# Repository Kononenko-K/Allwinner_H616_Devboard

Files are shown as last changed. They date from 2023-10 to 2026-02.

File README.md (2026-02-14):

# Allwinner_H616_Devboard
A minimalistic development board designed for the Cortex-A53 Allwinner H616 SoC using KiCad

<p align="center">
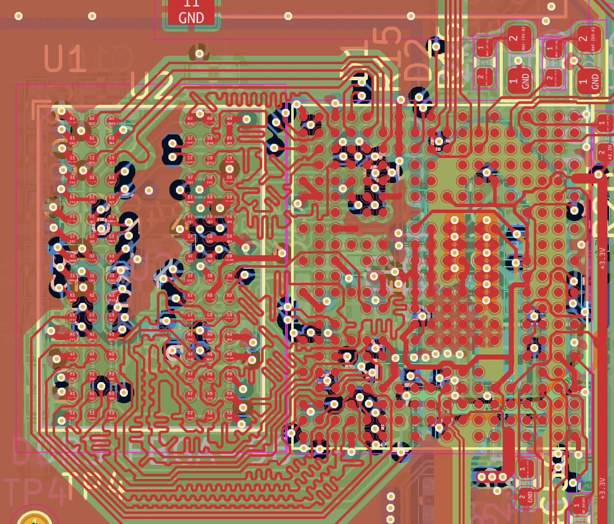
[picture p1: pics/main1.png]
     
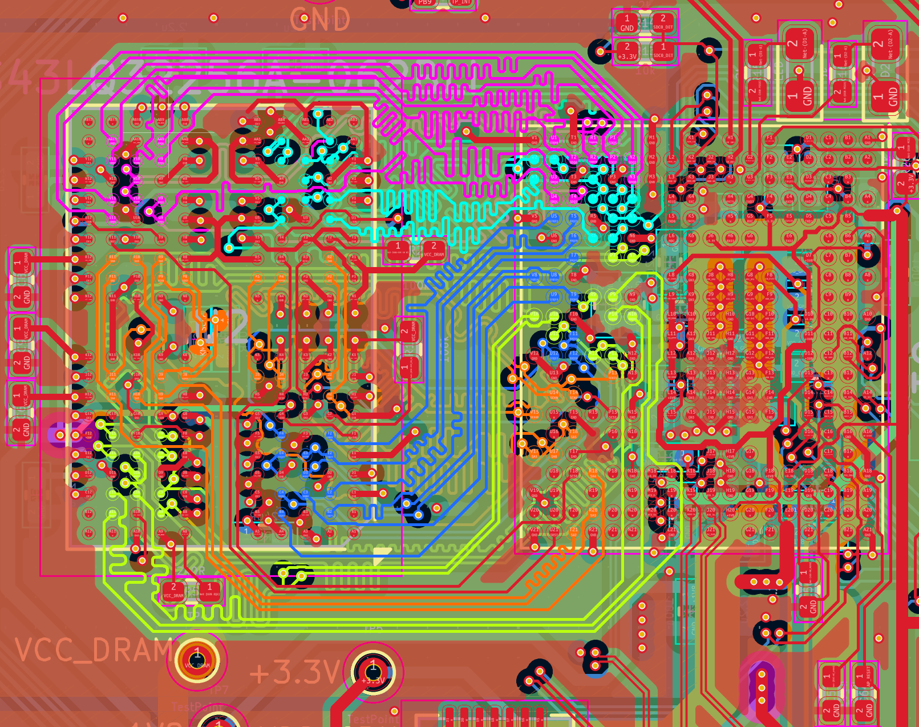
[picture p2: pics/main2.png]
     
</p>

## Overview
The goal of this project, based on the schematics of Orange Pi Zero 2 and Orange Pi Zero 3, was to create a minimalistic development board for the H616 SoC with a functional DDR3/LPDDR4 topology and power supply. This allows it to be used as a basic design that can be modified for specific applications.

## [Hardware](Hardware)
Both versions of the board are powered by the 64-bit 1.5GHz Quad-Core Cortex-A53 Allwinner H616 SoC, supporting either Allwinner H616 or its pin-to-pin compatible successor, Allwinner H618. The primary difference between these chips is the increased L2 cache size in the H618 model.
#### [DDR3 Version:](/Hardware/H616_DDR3)
<p align="center">
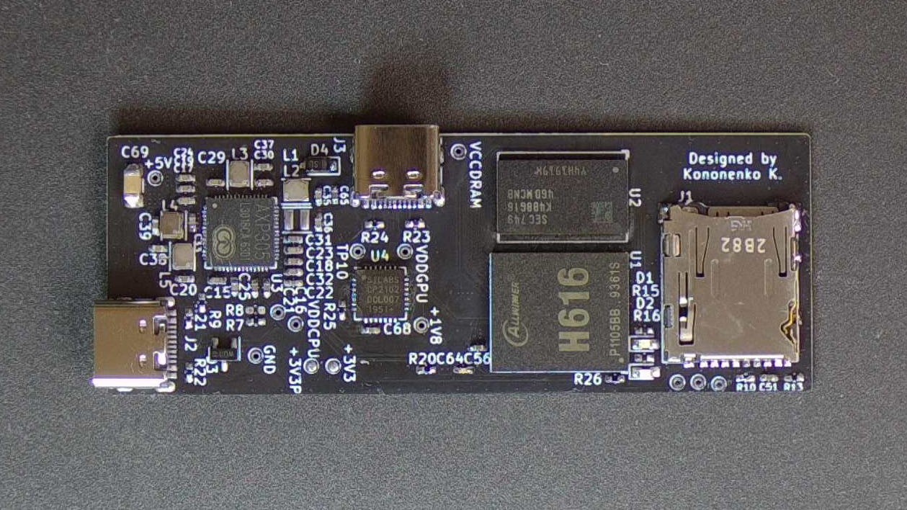
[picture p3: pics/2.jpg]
     
</p>

The DDR3 variant features a compact design optimized for simplicity and ease of learning. Key components include:

- **Memory:** Up to 8 Gbit (1 GB) of BGA-96 16x DDR3 RAM
- **Power Management:** X-Powers AXP305 PMIC
- **Connectivity:** Micro SD slot, USB HS Host connector
- **Communication:** Integrated CP2102 USB-UART converter

#### [LPDDR4 Version:](/Hardware/H616_LPDDR4)
<p align="center">
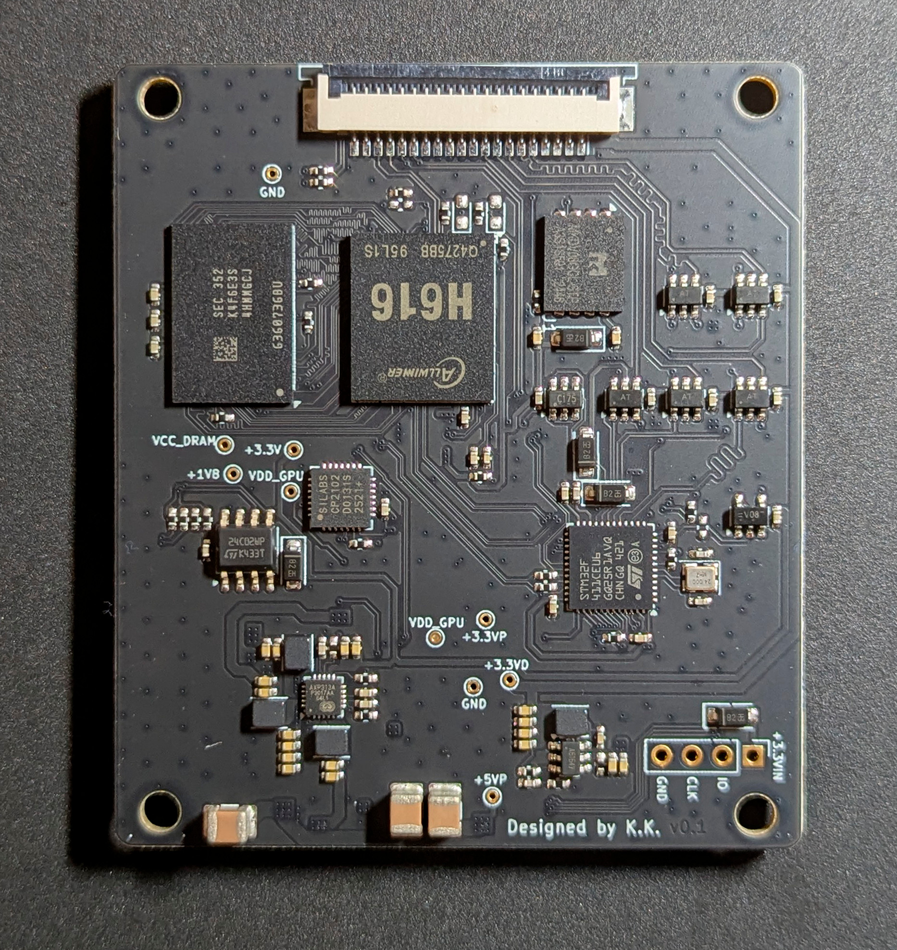
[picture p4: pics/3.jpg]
     
</p>

The LPDDR4 variant offers enhanced capabilities tailored for my specific application, while also remaining suitable for educational use:

- **Memory:** Up to 32 Gbit (4 GB) of BGA-200 32x LPDDR4 RAM
- **Power Management:** X-Powers AXP313A PMIC
- **Storage:** Integrated SD2.0 Flash Memory chip and MicroSD slot for flexible storage options
- **Auxiliary Processing:** Cortex-M4 STM32 microcontroller for additional processing tasks
- **Communication:** Integrated CP2102 USB-UART converter

To power the board via USB and connect external devices, a custom [USB board adapter](/Hardware/Debug_Adapter) is available.

### **Manufacturing specifications:**
- **Layers:** 4-layer design  
- **Trace/Space:** 3.5/3.5 mil  
- **Via Sizes:** 0.35/0.15 mm 
- **Prepreg:** 80u  

There are PDF documents available for both [DDR3](/Hardware/H616_DDR3/project.pdf) and [LPDDR4](/Hardware/H616_LPDDR4/project.pdf) versions.

## Software

### **Building from Mainline:**
#### Arm Trusted Firmware (TF-A):
- Source: [here](https://git.trustedfirmware.org/TF-A/trusted-firmware-a.git/)
```sh
make CROSS_COMPILE=aarch64-linux-gnu- PLAT=sun50i_h616 RESET_TO_BL31=1
```
After building, copy the `bl31.bin` file to the U-Boot sources directory.

#### U-Boot:
- Source: [here](https://github.com/u-boot/u-boot)
```sh
make ARCH=arm CROSS_COMPILE=aarch64-linux-gnu- orangepi_zero2_defconfig
make ARCH=arm CROSS_COMPILE=aarch64-linux-gnu- BL31=bl31.bin
```

#### Linux Kernel:
- Source: [www.kernel.org](http://www.kernel.org)
```sh
make ARCH=arm64 CROSS_COMPILE=aarch64-linux-gnu- defconfig
make ARCH=arm64 CROSS_COMPILE=aarch64-linux-gnu- Image modules dtbs
```

#### Rootfs:
Example sources for arm64 rootfs:
- [rcn-ee.com](https://rcn-ee.com/rootfs/eewiki/minfs)
- [Linaro.org](https://releases.linaro.org/openembedded/images/)

#### Preparing SD Card:
1. Create two partitions: a small fat32 for boot files and an ext4 for rootfs.
2. Write U-Boot to the card:
```sh
sudo dd if=/dev/zero of=/dev/mmcblk0 bs=1k count=1023 seek=1
sudo dd if=u-boot-sunxi-with-spl.bin of=/dev/mmcblk0 bs=1024 seek=8
```
3. Copy dtb and kernel image to the first partition, then unpack rootfs to the second.

If you prefer to load U-Boot into RAM and execute it directly over USB without using an SD card, you can use the `sunxi-fel` utility:  
   ```sh
   sudo sunxi-fel uboot u-boot-sunxi-with-spl.bin
   ```  
This method is useful for testing or when bypassing the SD card for some reason.

#### Booting from U-Boot:
Enter these commands in the U-Boot console:
```sh
setenv bootargs console=ttyS0,115200 root=/dev/mmcblk0p2 rw rootwait
setenv bootcmd "mmc rescan; fatload mmc 0:1 0x46000000 Image; fatload mmc 0:1 0x49000000 sun50i-h616-orangepi-zero2.dtb; booti 0x46000000 - 0x49000000"
```
Use a `boot.scr` file for automatic booting.

### **Using Buildroot:**
For LPDDR4 version:
```sh
make orangepi_zero3_defconfig
```
For DDR3 versions, modify the config:
```sh
BR2_LINUX_KERNEL_INTREE_DTS_NAME="allwinner/sun50i-h616-orangepi-zero2.dts"
BR2_TARGET_UBOOT_BOARD_DEFCONFIG="orangepi_zero2"
```
Download sources with `make source`, then build.

## License
- The **Hardware** in this project is licensed under the [CERN Open Hardware Licence Permissive (CERN OHL-P)](LICENSE).

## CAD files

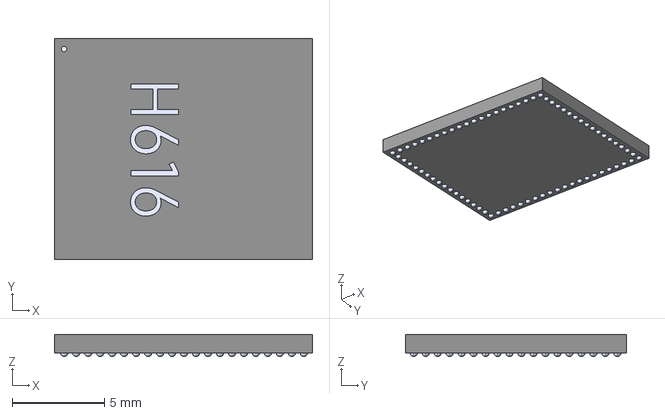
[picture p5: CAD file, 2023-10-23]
Hardware/H616_DDR3/SoC_H616.step
14.0 x 12.0 x 1.20 mm

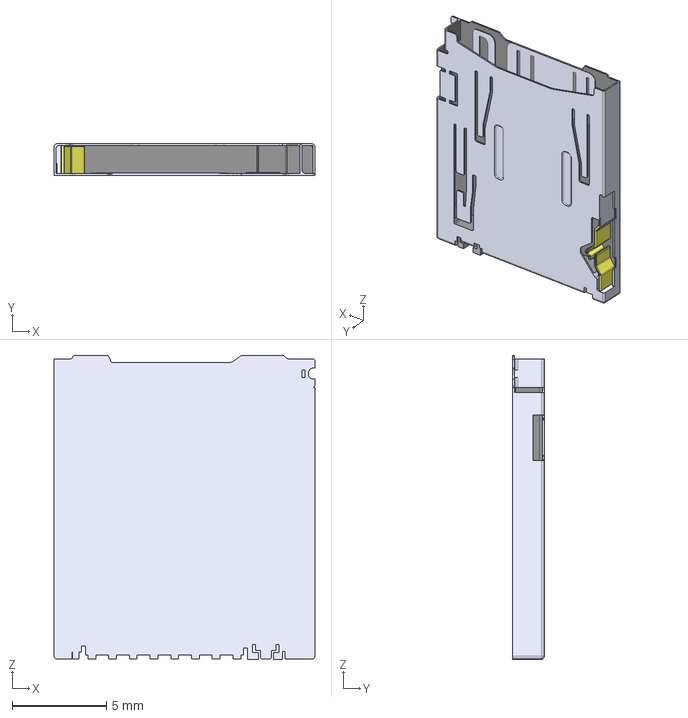
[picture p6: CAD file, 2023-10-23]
Hardware/H616_LPDDR4/MicroSD_DM3AT.step
13.8 x 1.68 x 16.2 mm

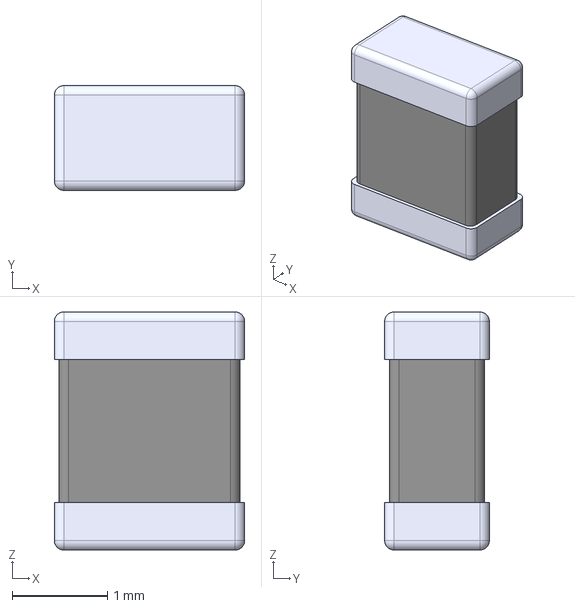
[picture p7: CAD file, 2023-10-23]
Hardware/H616_LPDDR4/Inductor_2520.step
2.00 x 1.10 x 2.50 mm

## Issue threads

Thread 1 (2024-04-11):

BOM

TechyGuy17, 2024-04-11:
Hello!

I love this project, been looking for a good and simple h616 circuit and this is great!!

Do you have any recommendation regarding sourcing? For example the AXP305 seems to have dissapered from lcsc, do you solder it yourself?

And is there a reason you use a 25mhz reference clock instead of the recommended 24 in the datasheet of the h616?

Thanks!

Closed 2024-04-18.

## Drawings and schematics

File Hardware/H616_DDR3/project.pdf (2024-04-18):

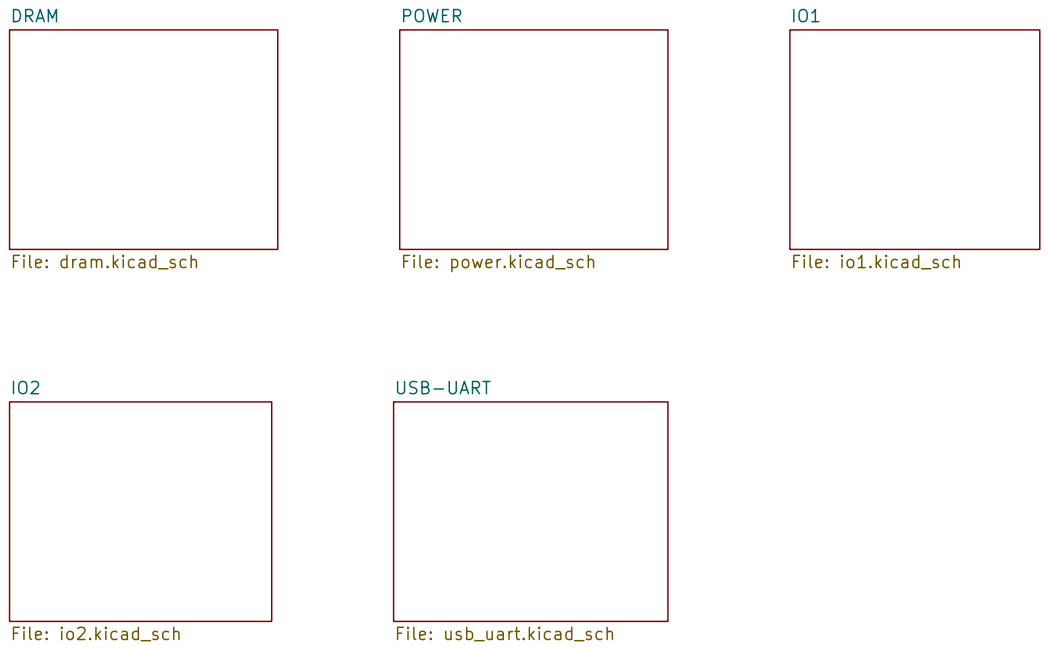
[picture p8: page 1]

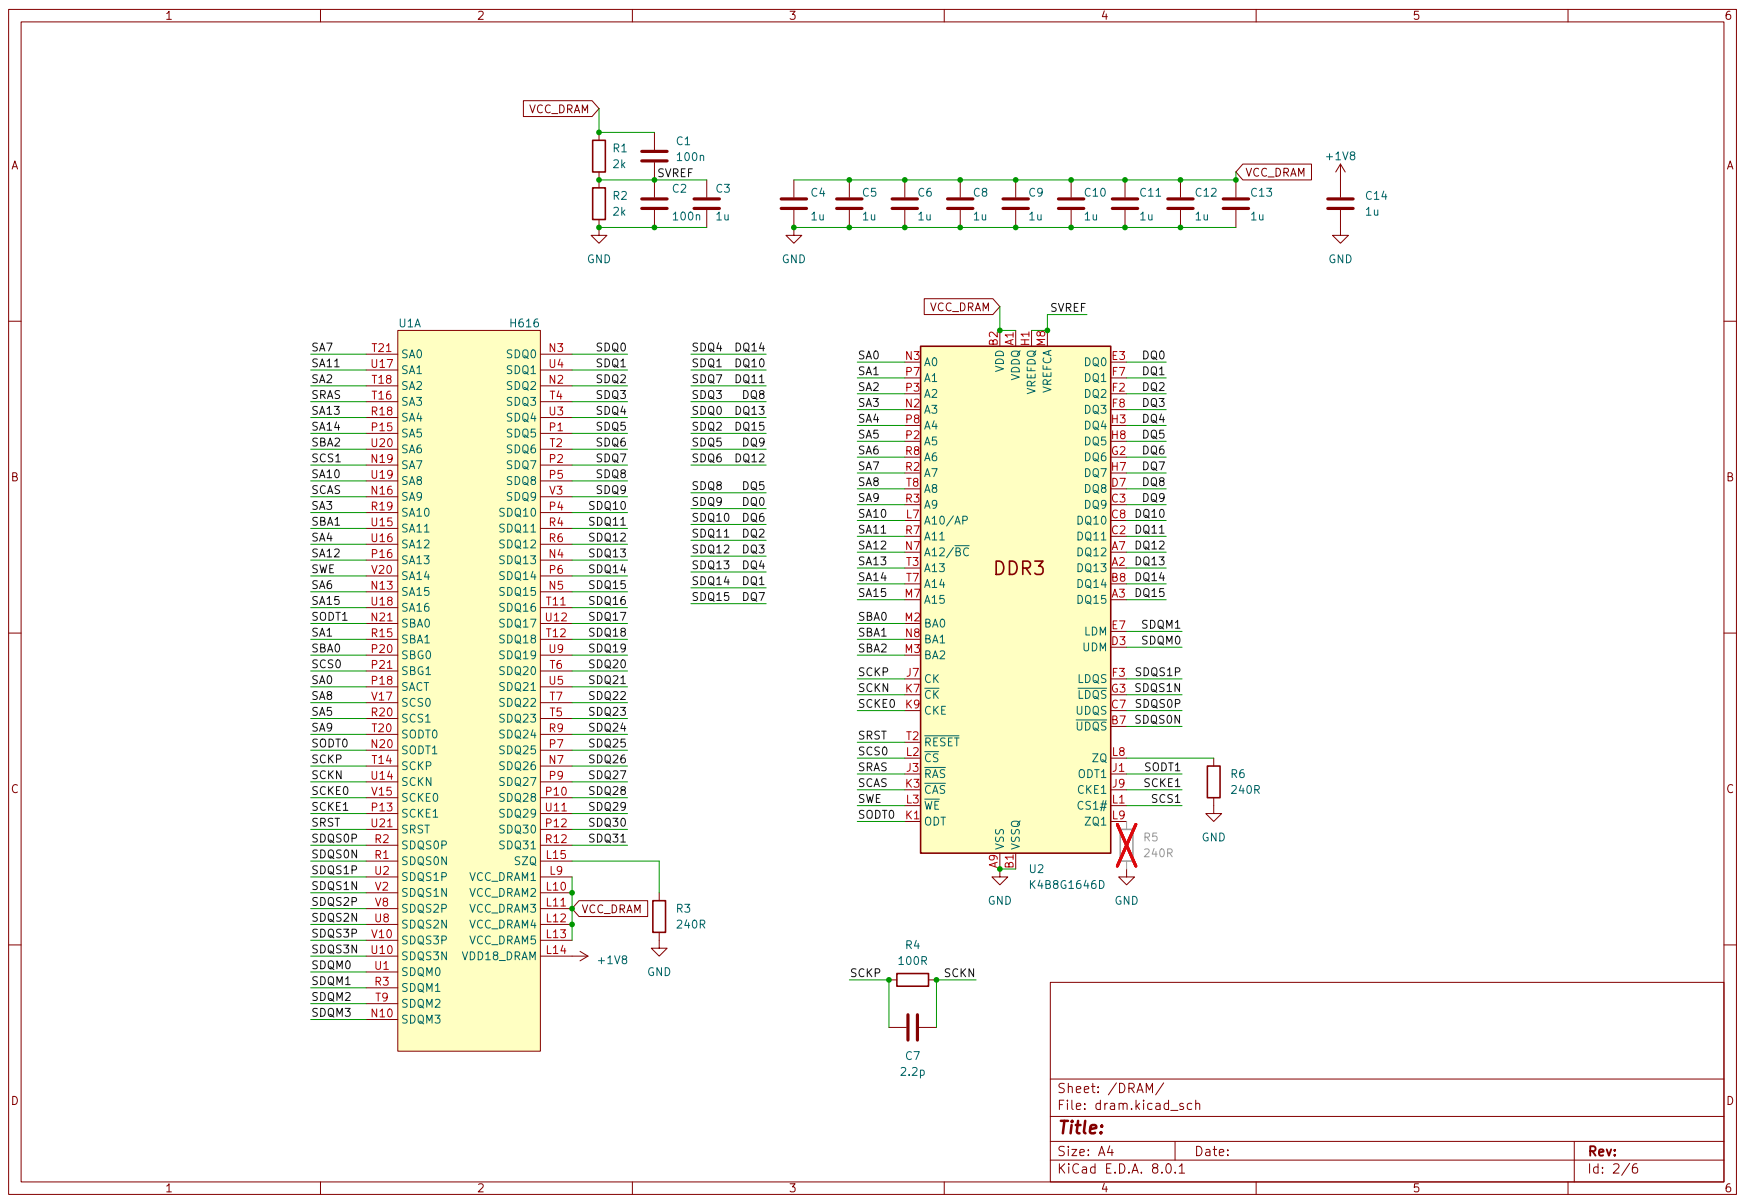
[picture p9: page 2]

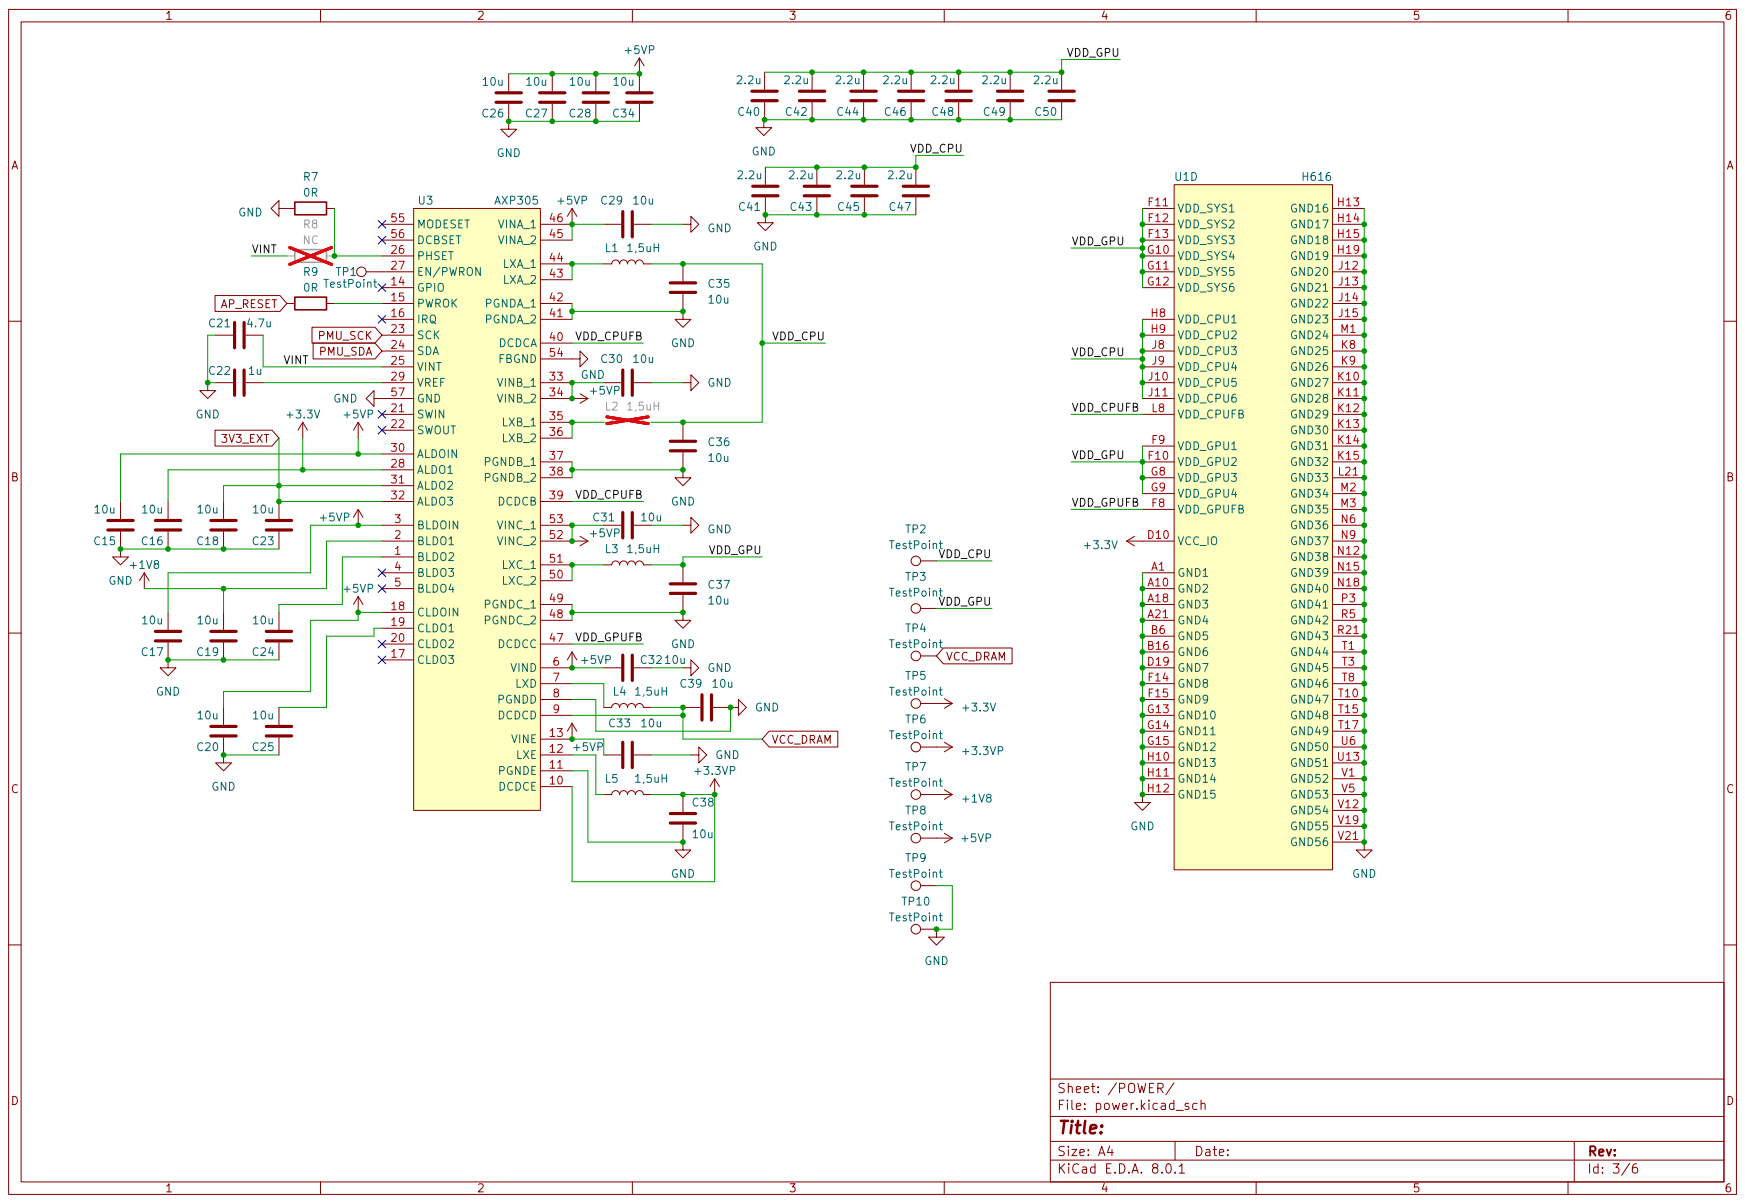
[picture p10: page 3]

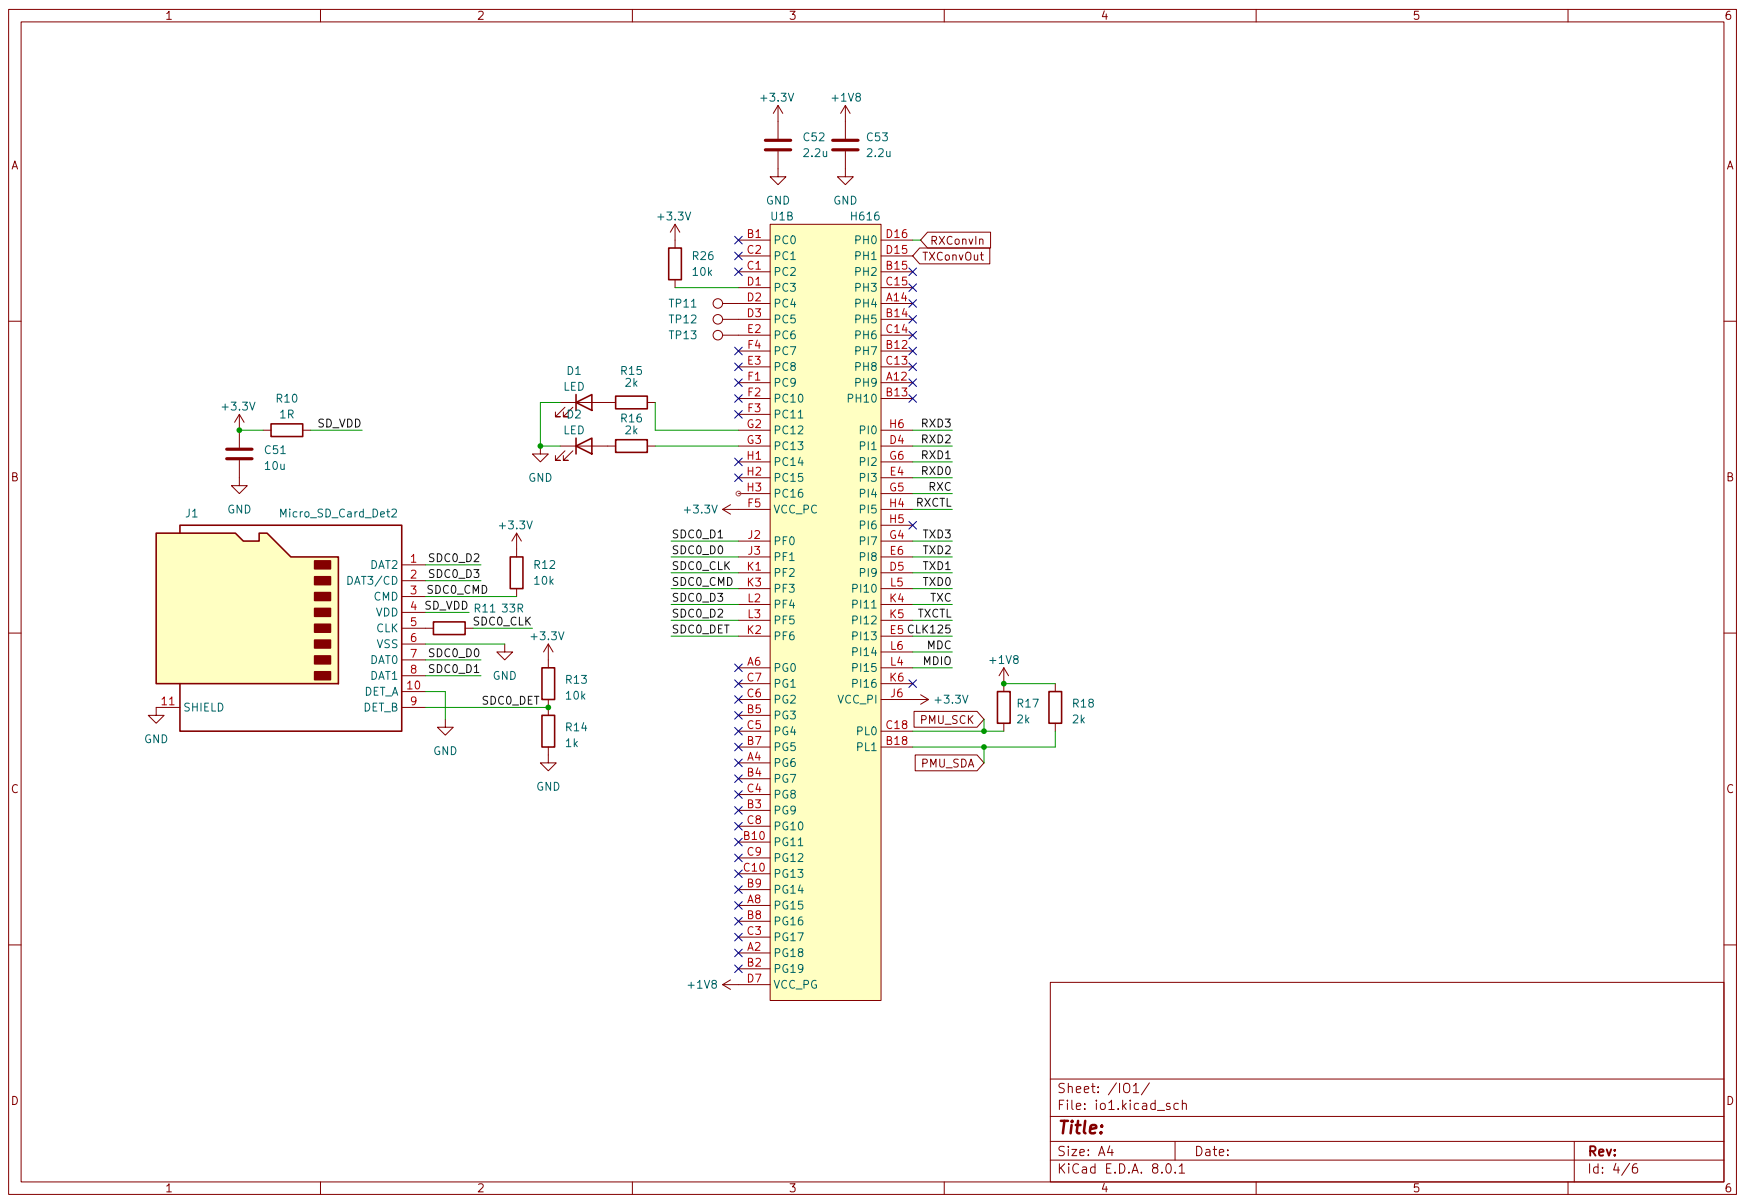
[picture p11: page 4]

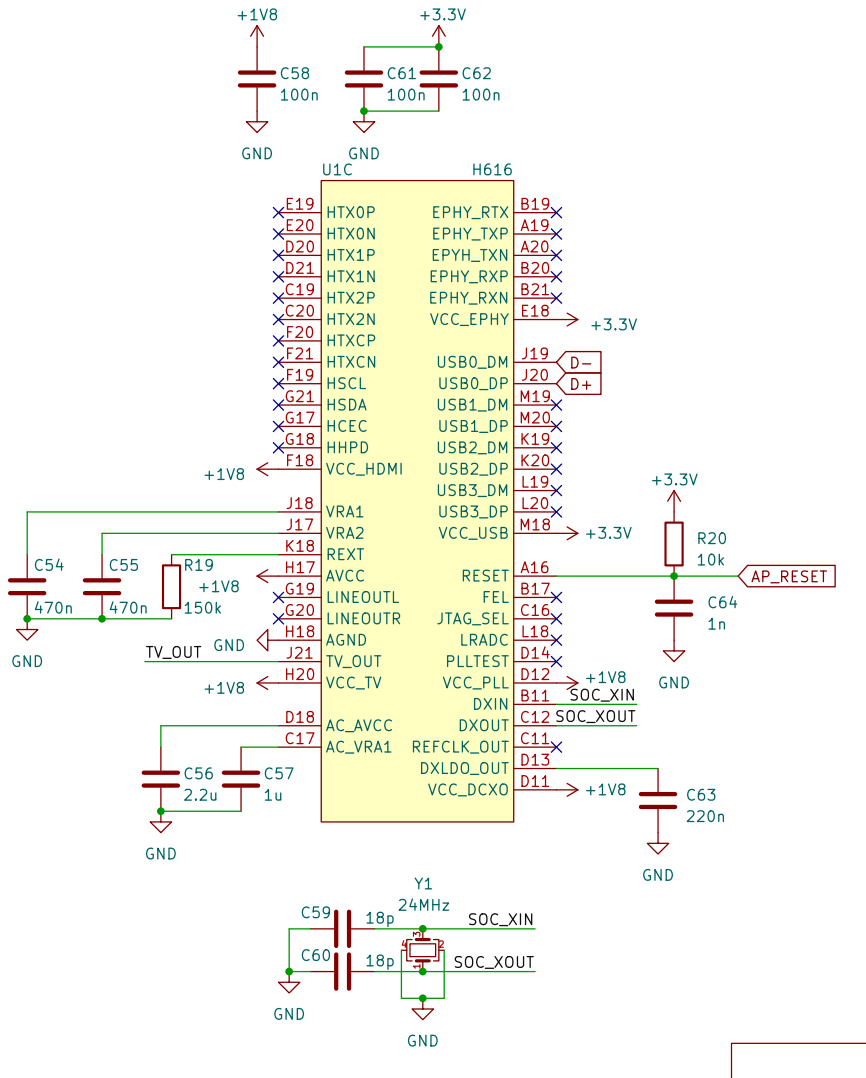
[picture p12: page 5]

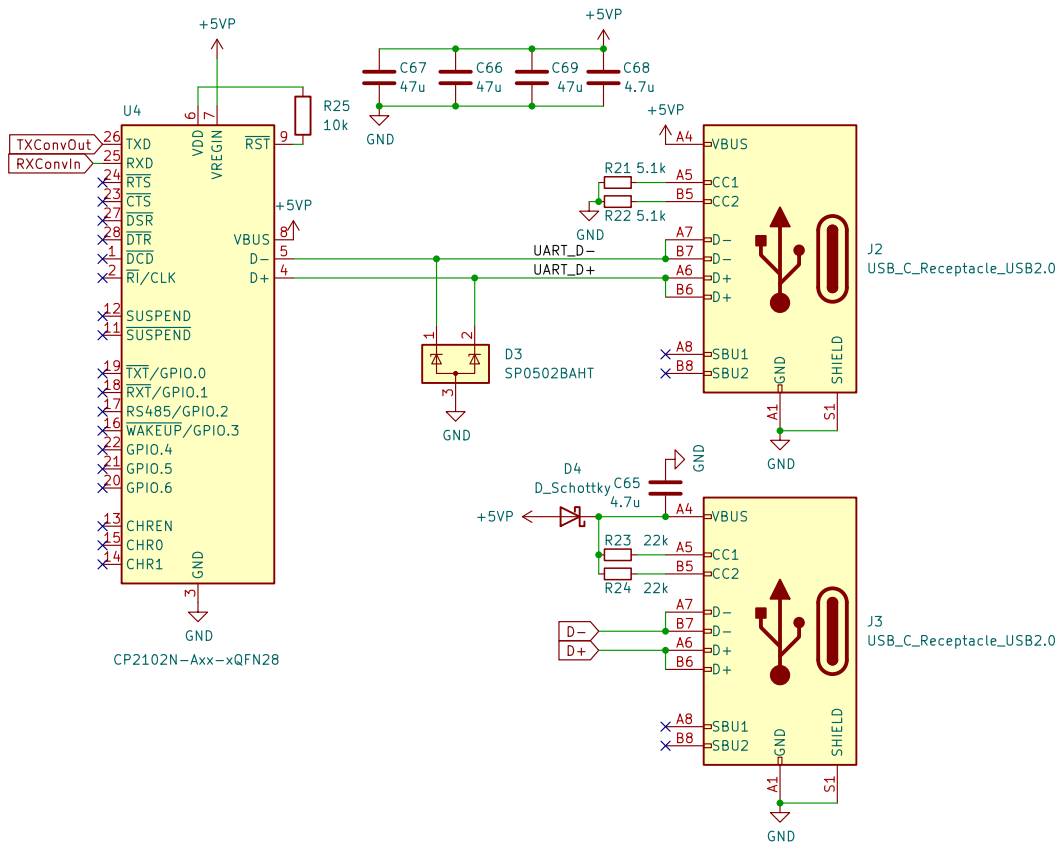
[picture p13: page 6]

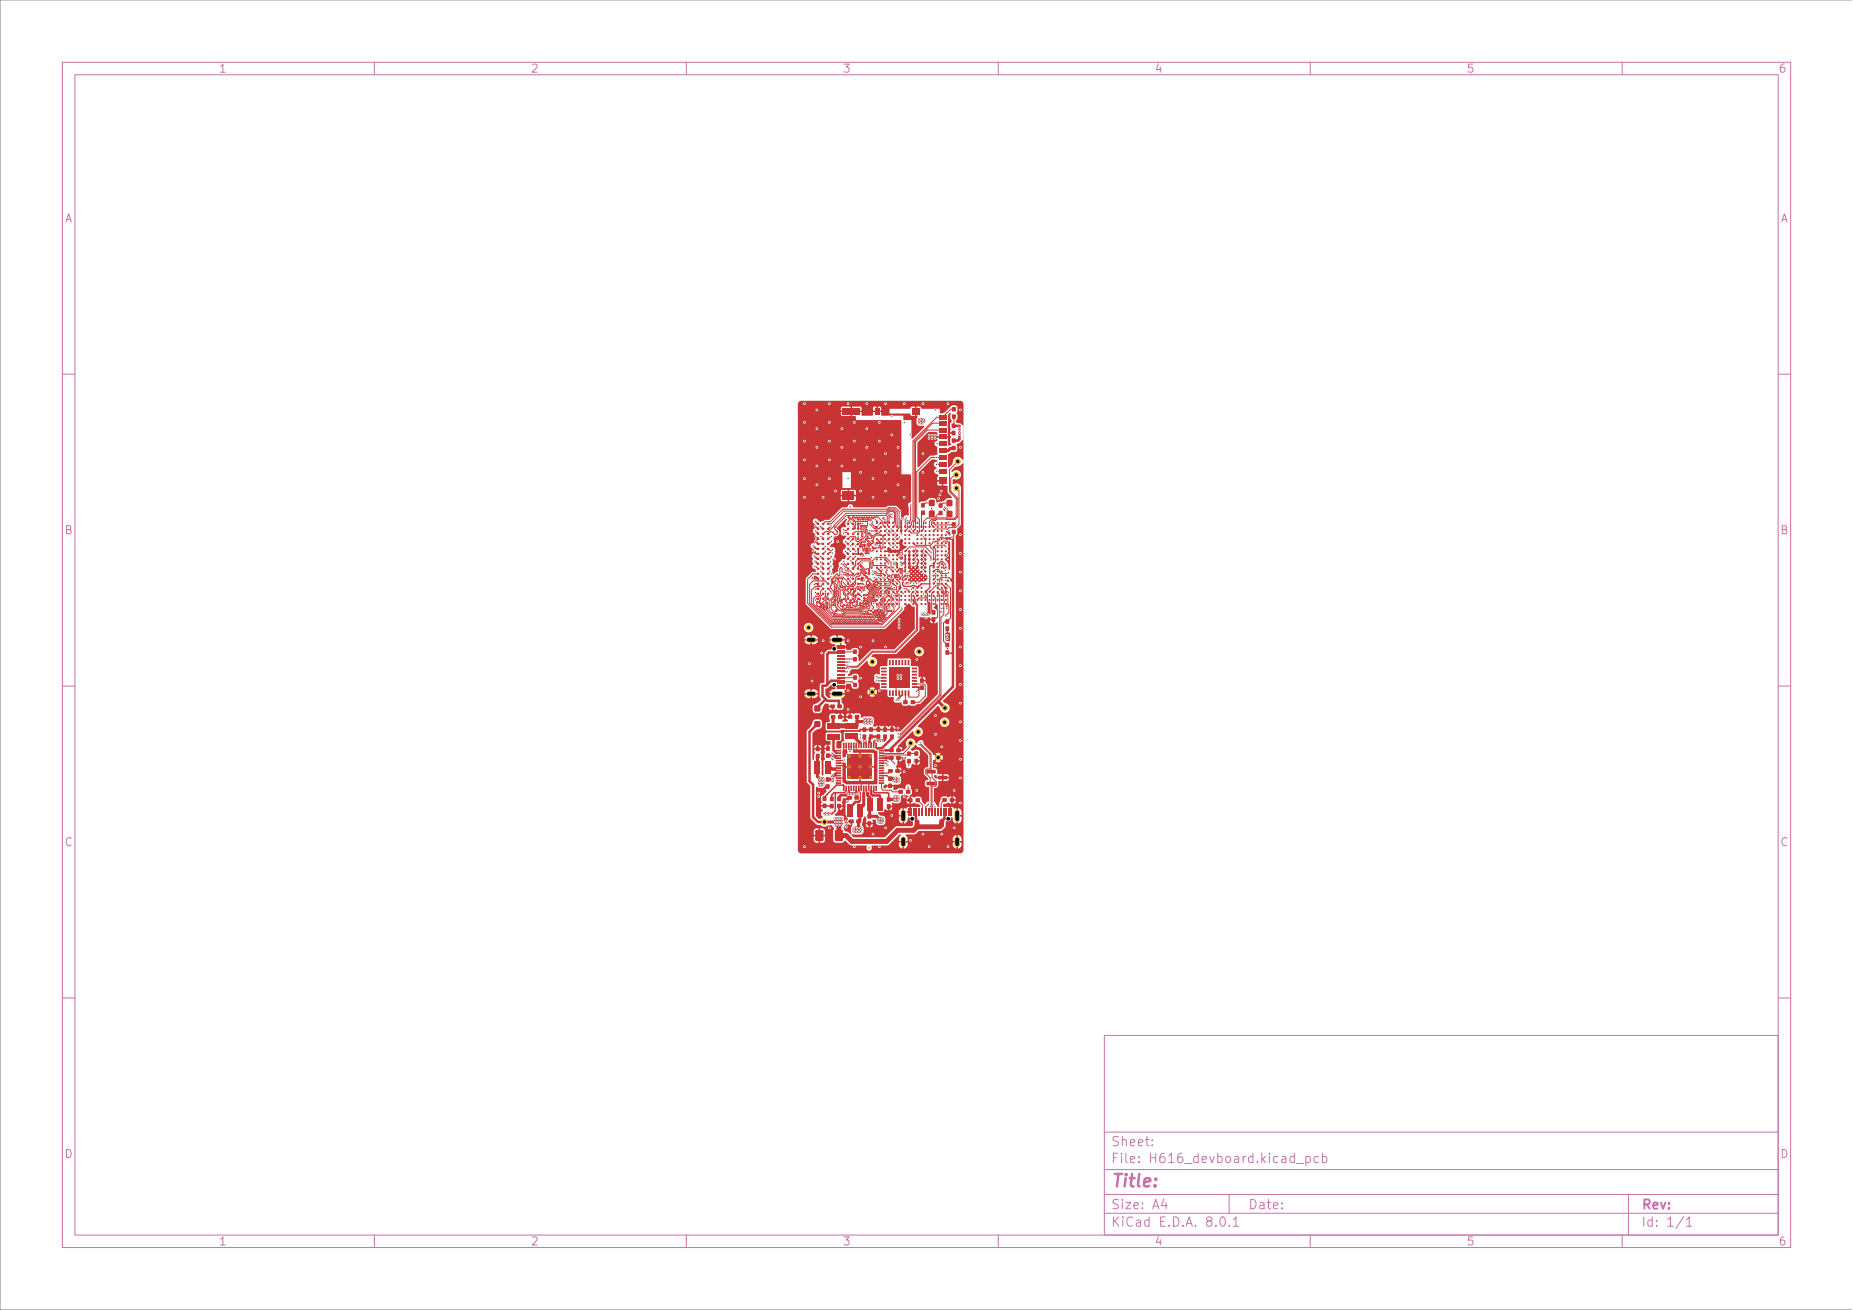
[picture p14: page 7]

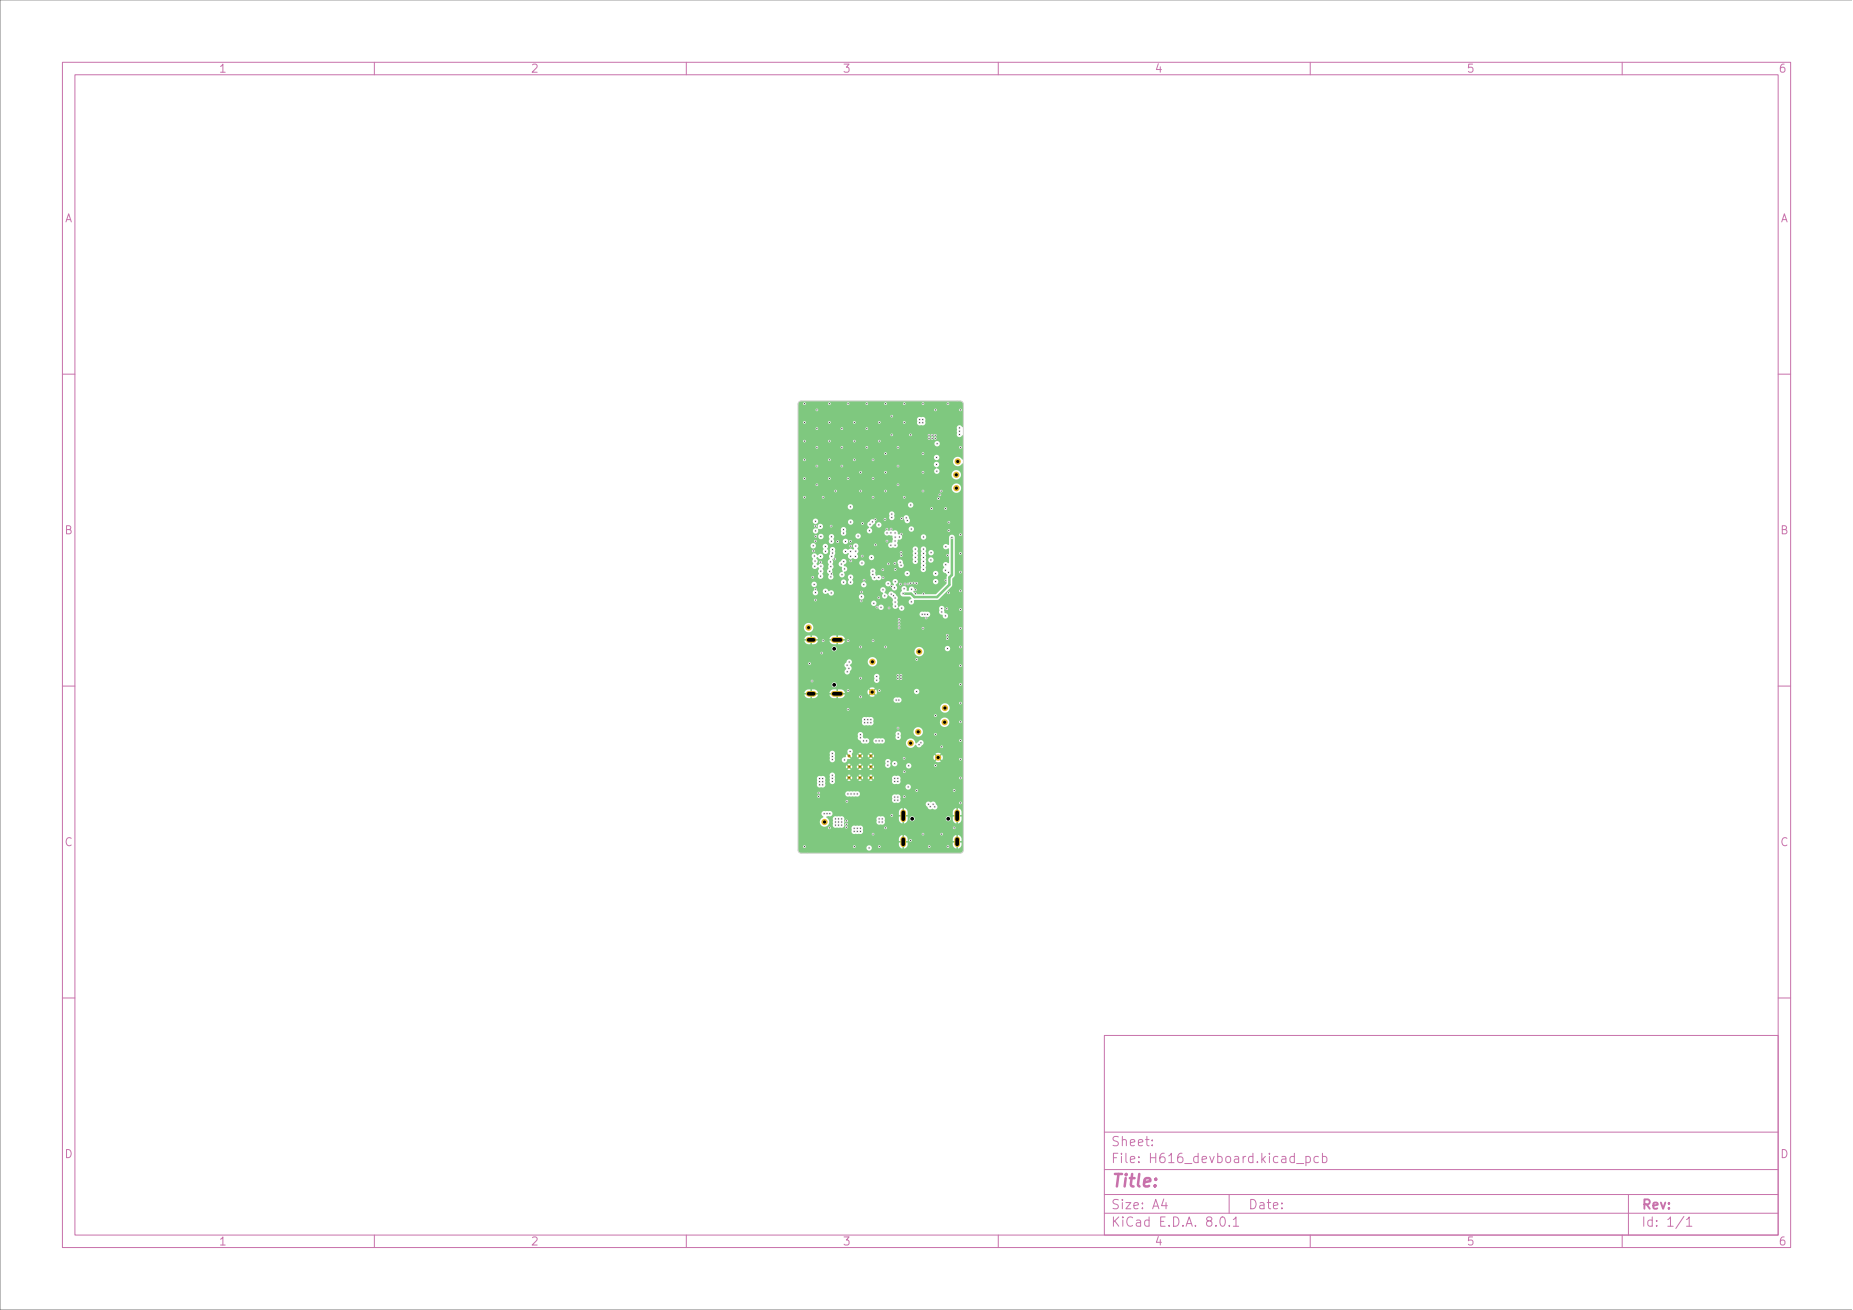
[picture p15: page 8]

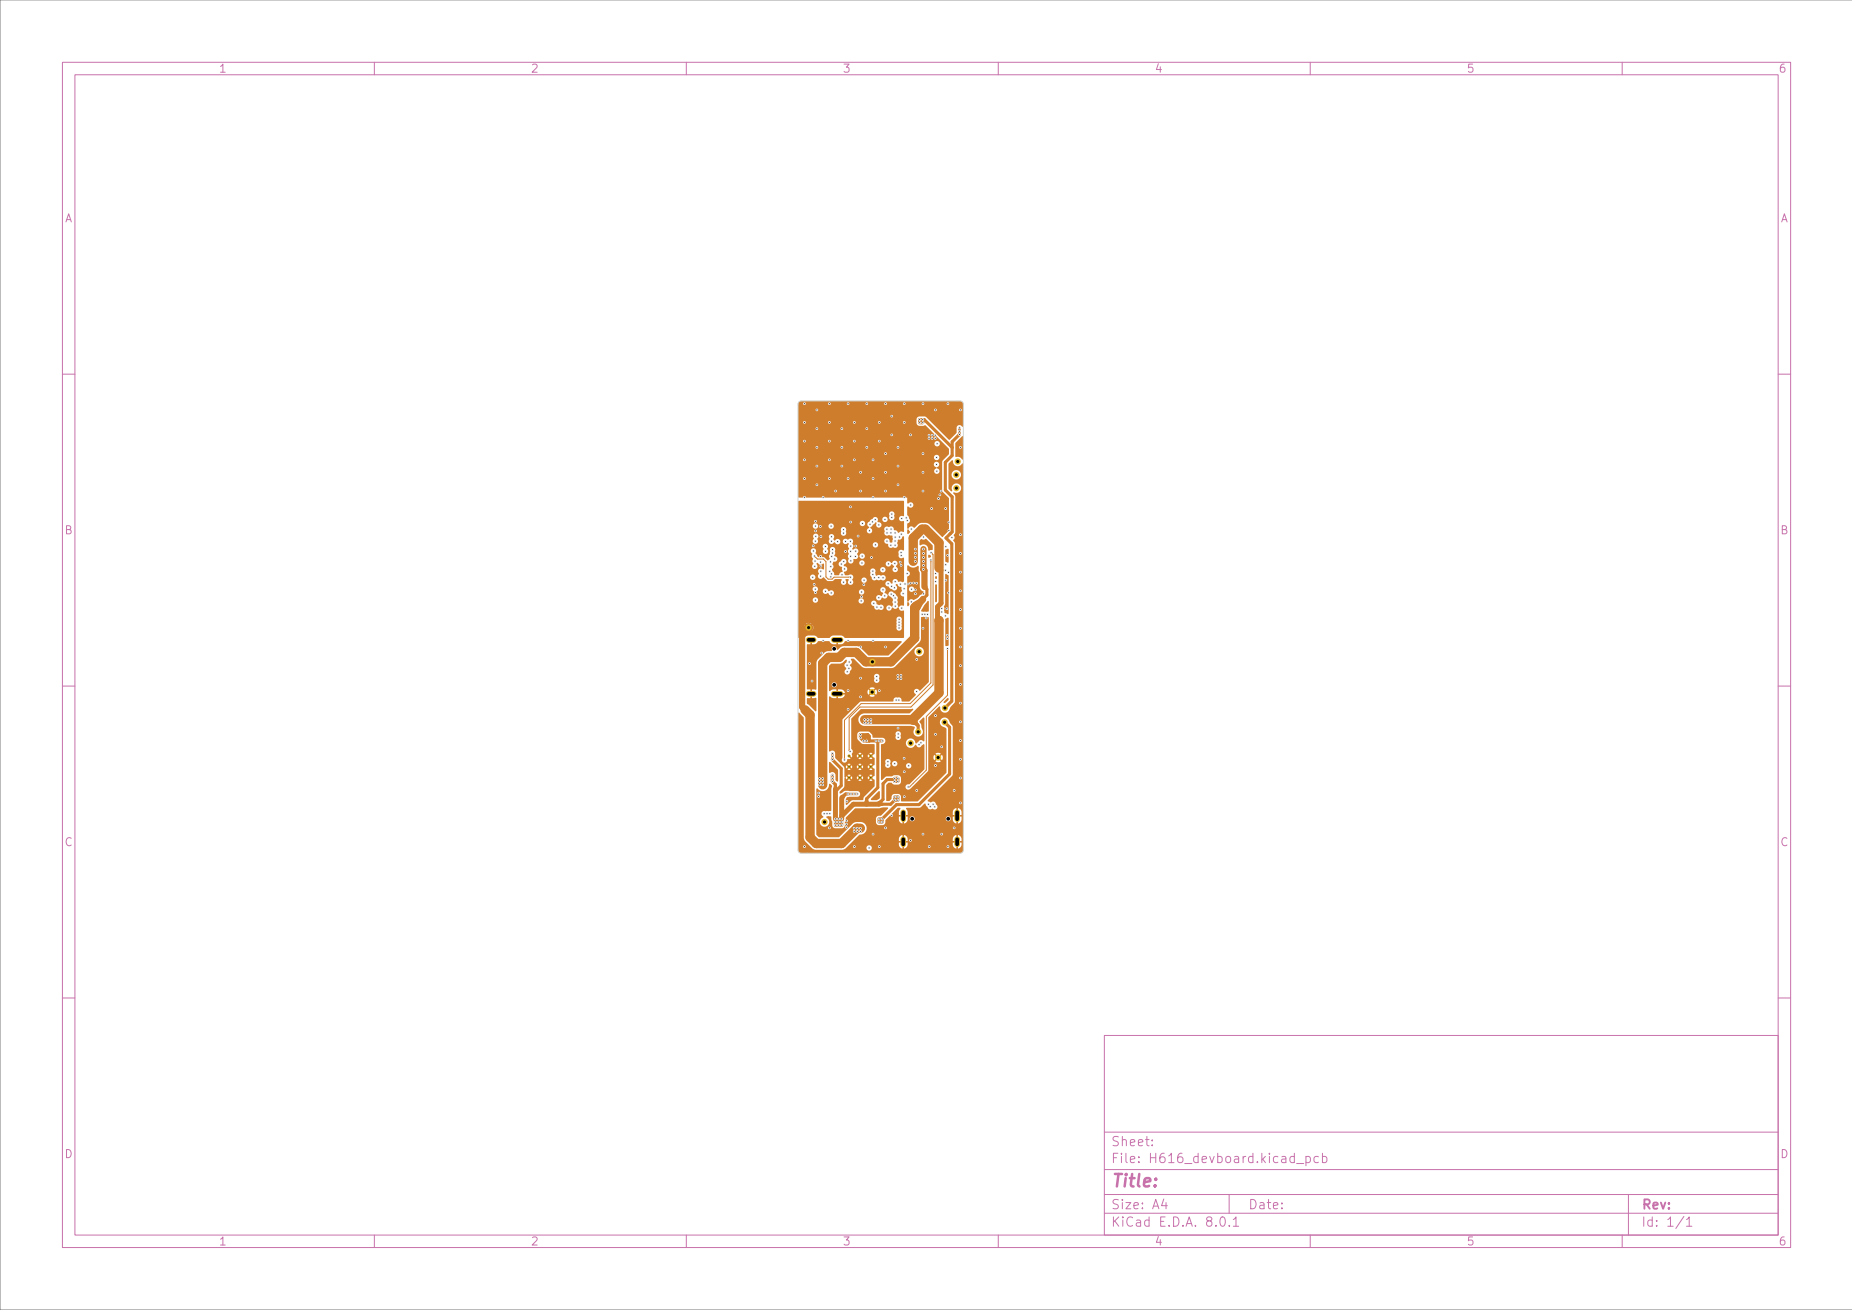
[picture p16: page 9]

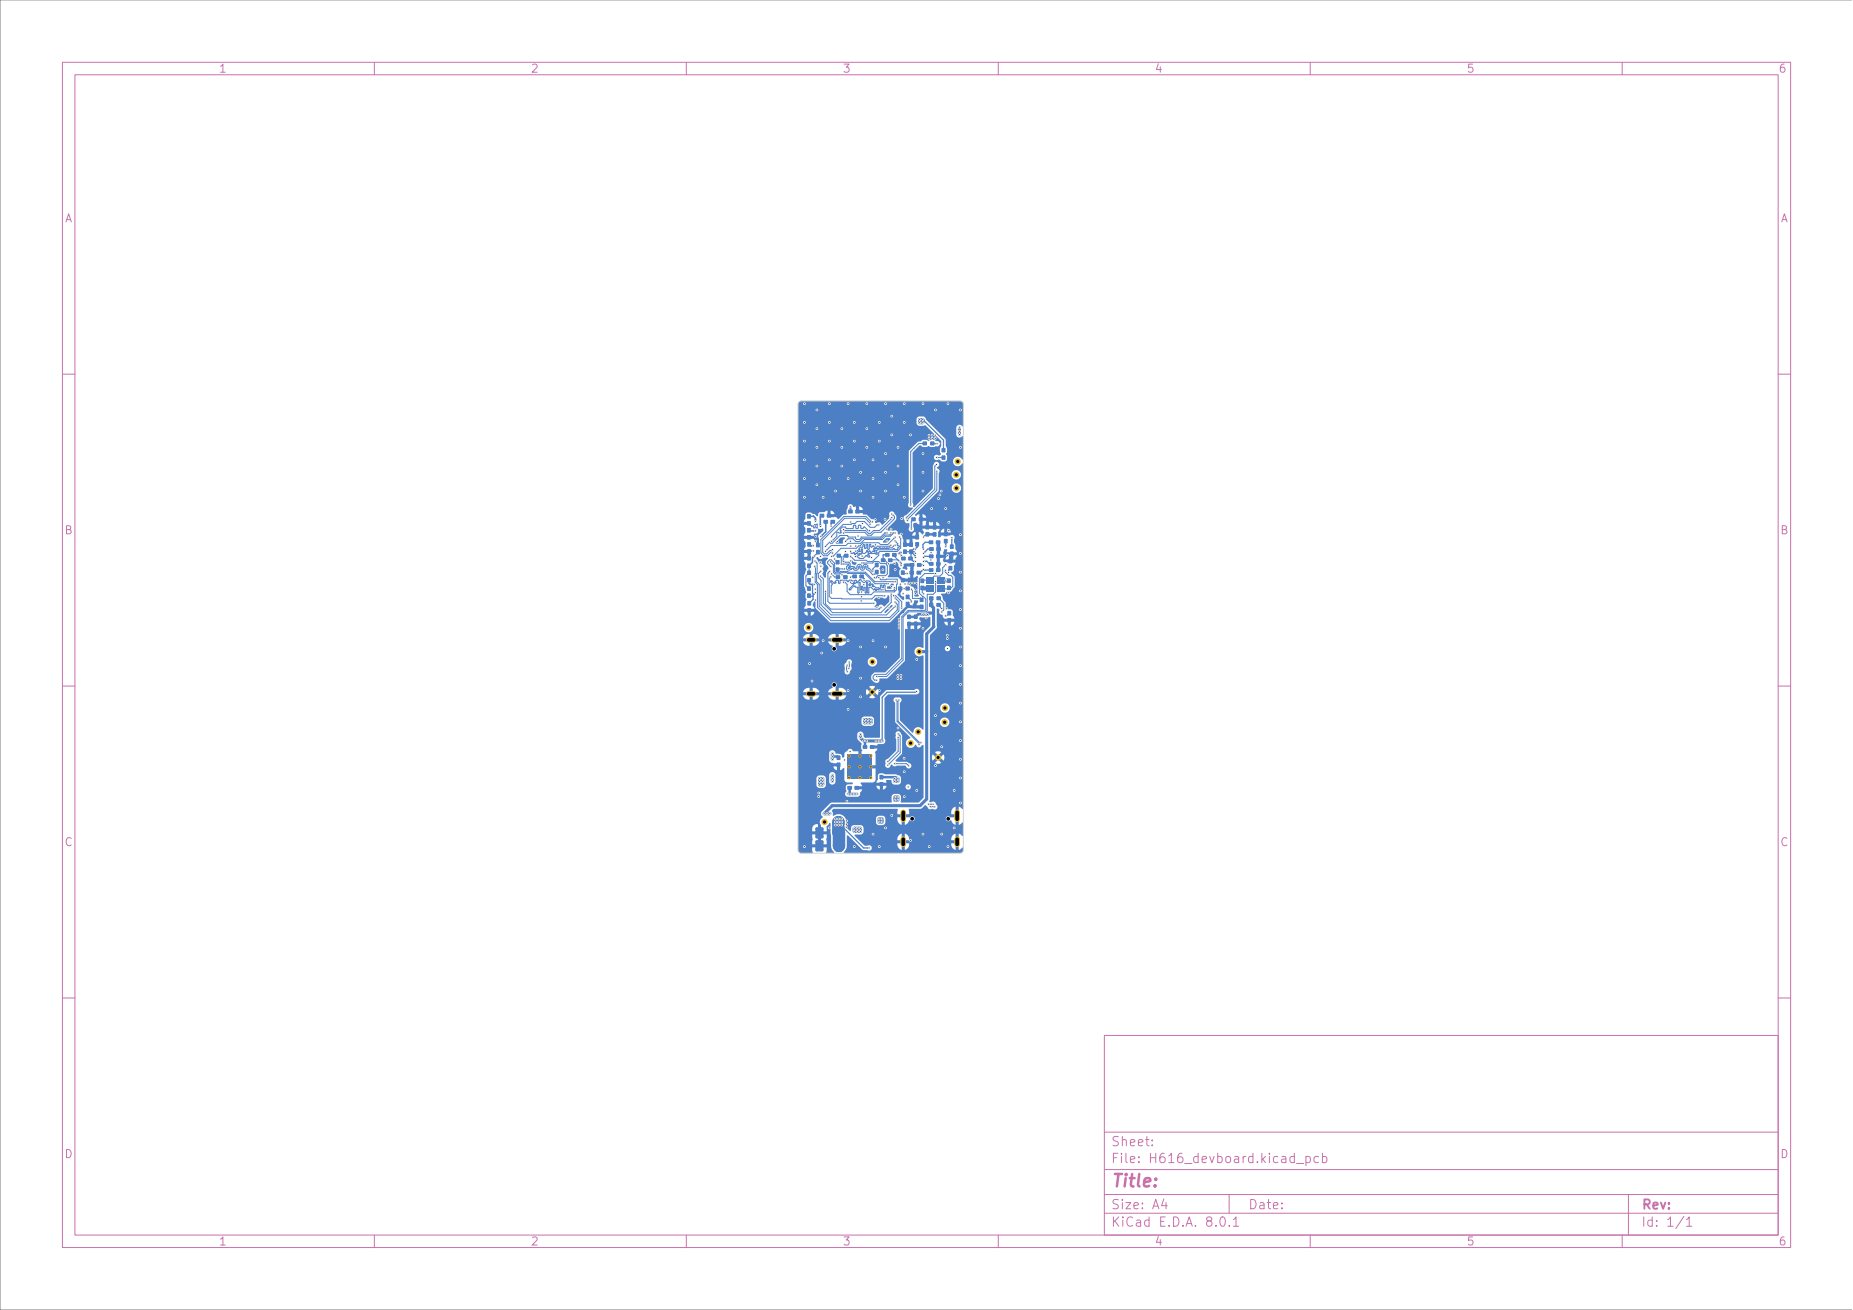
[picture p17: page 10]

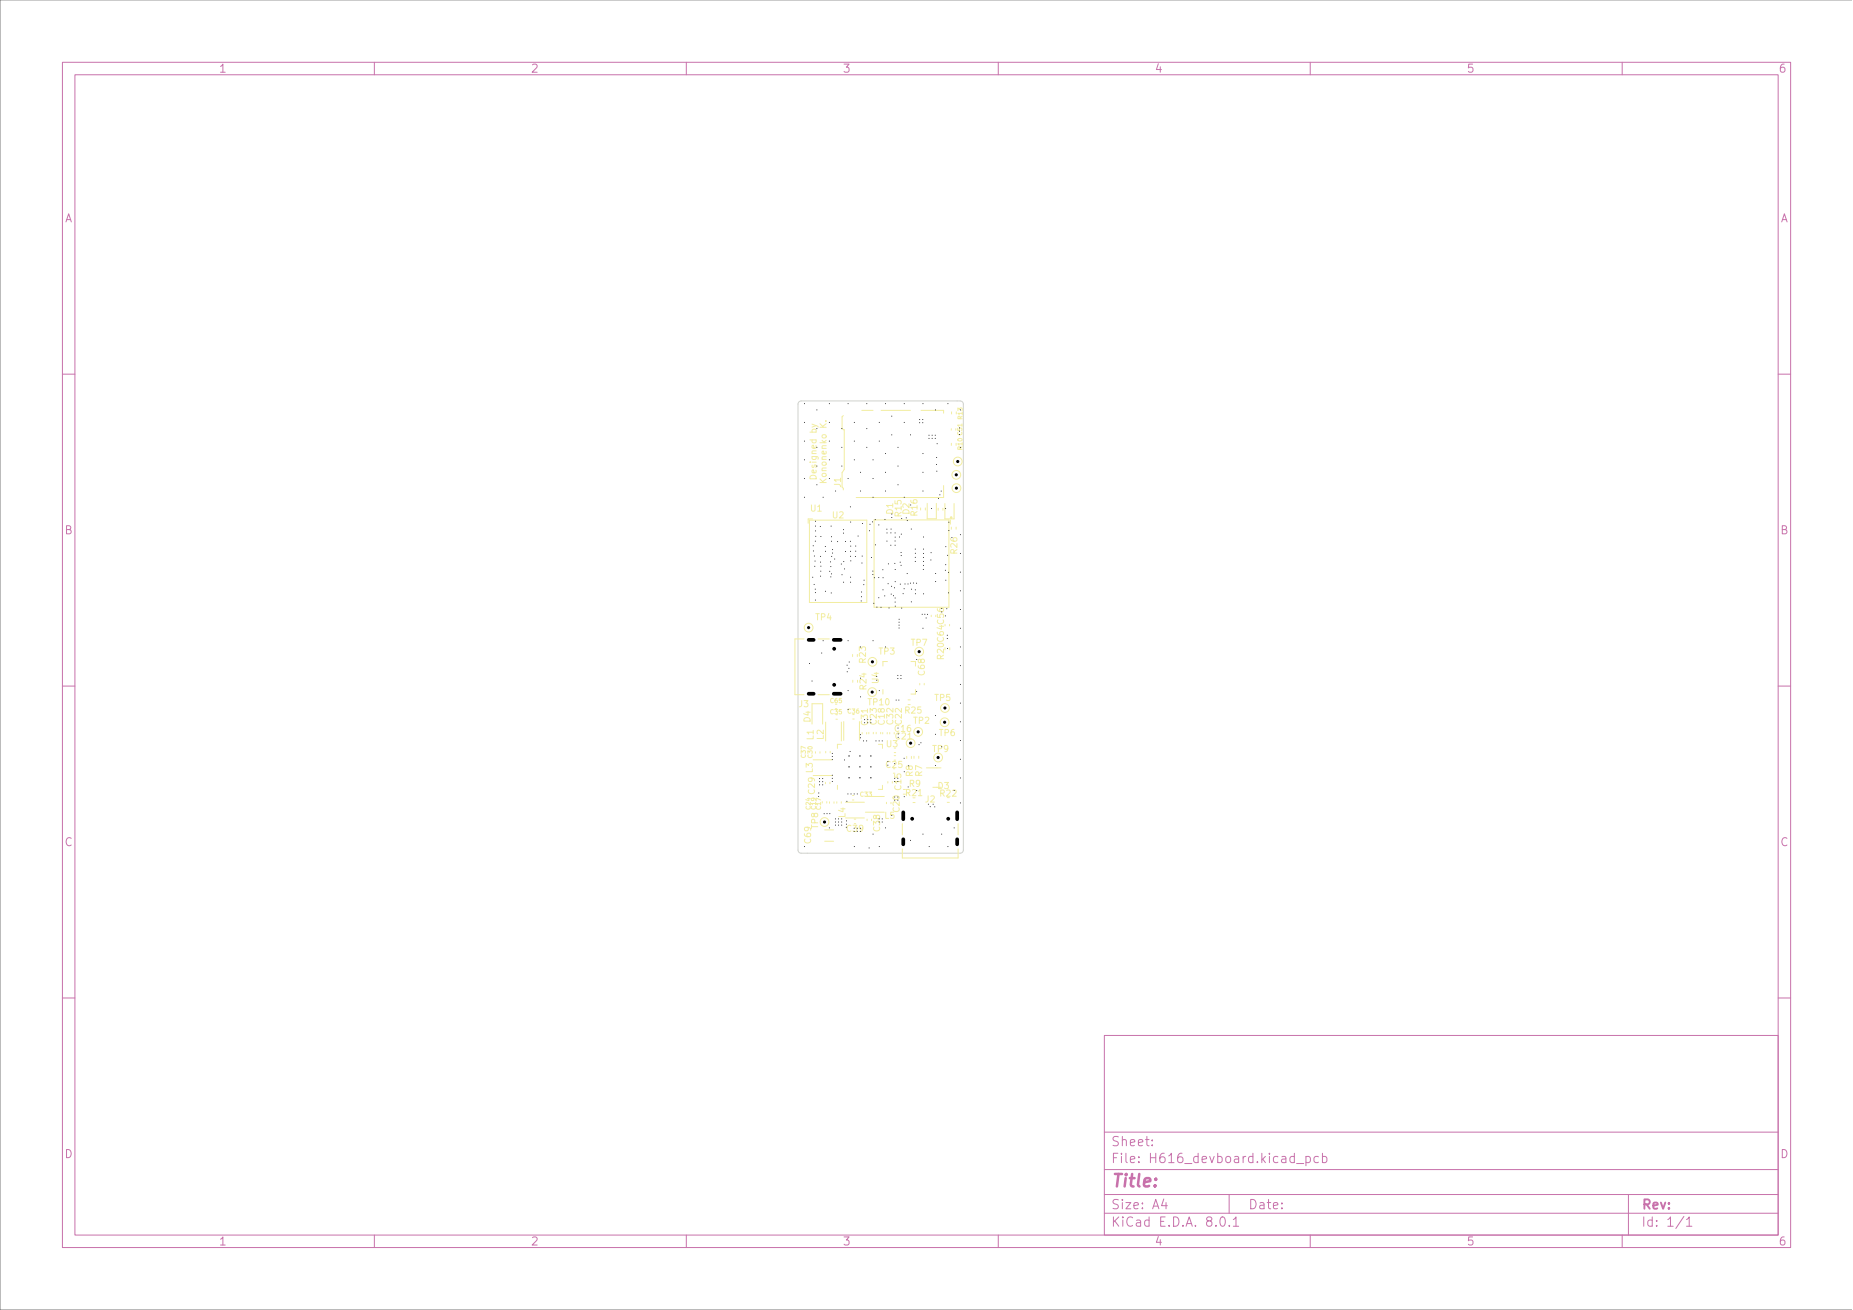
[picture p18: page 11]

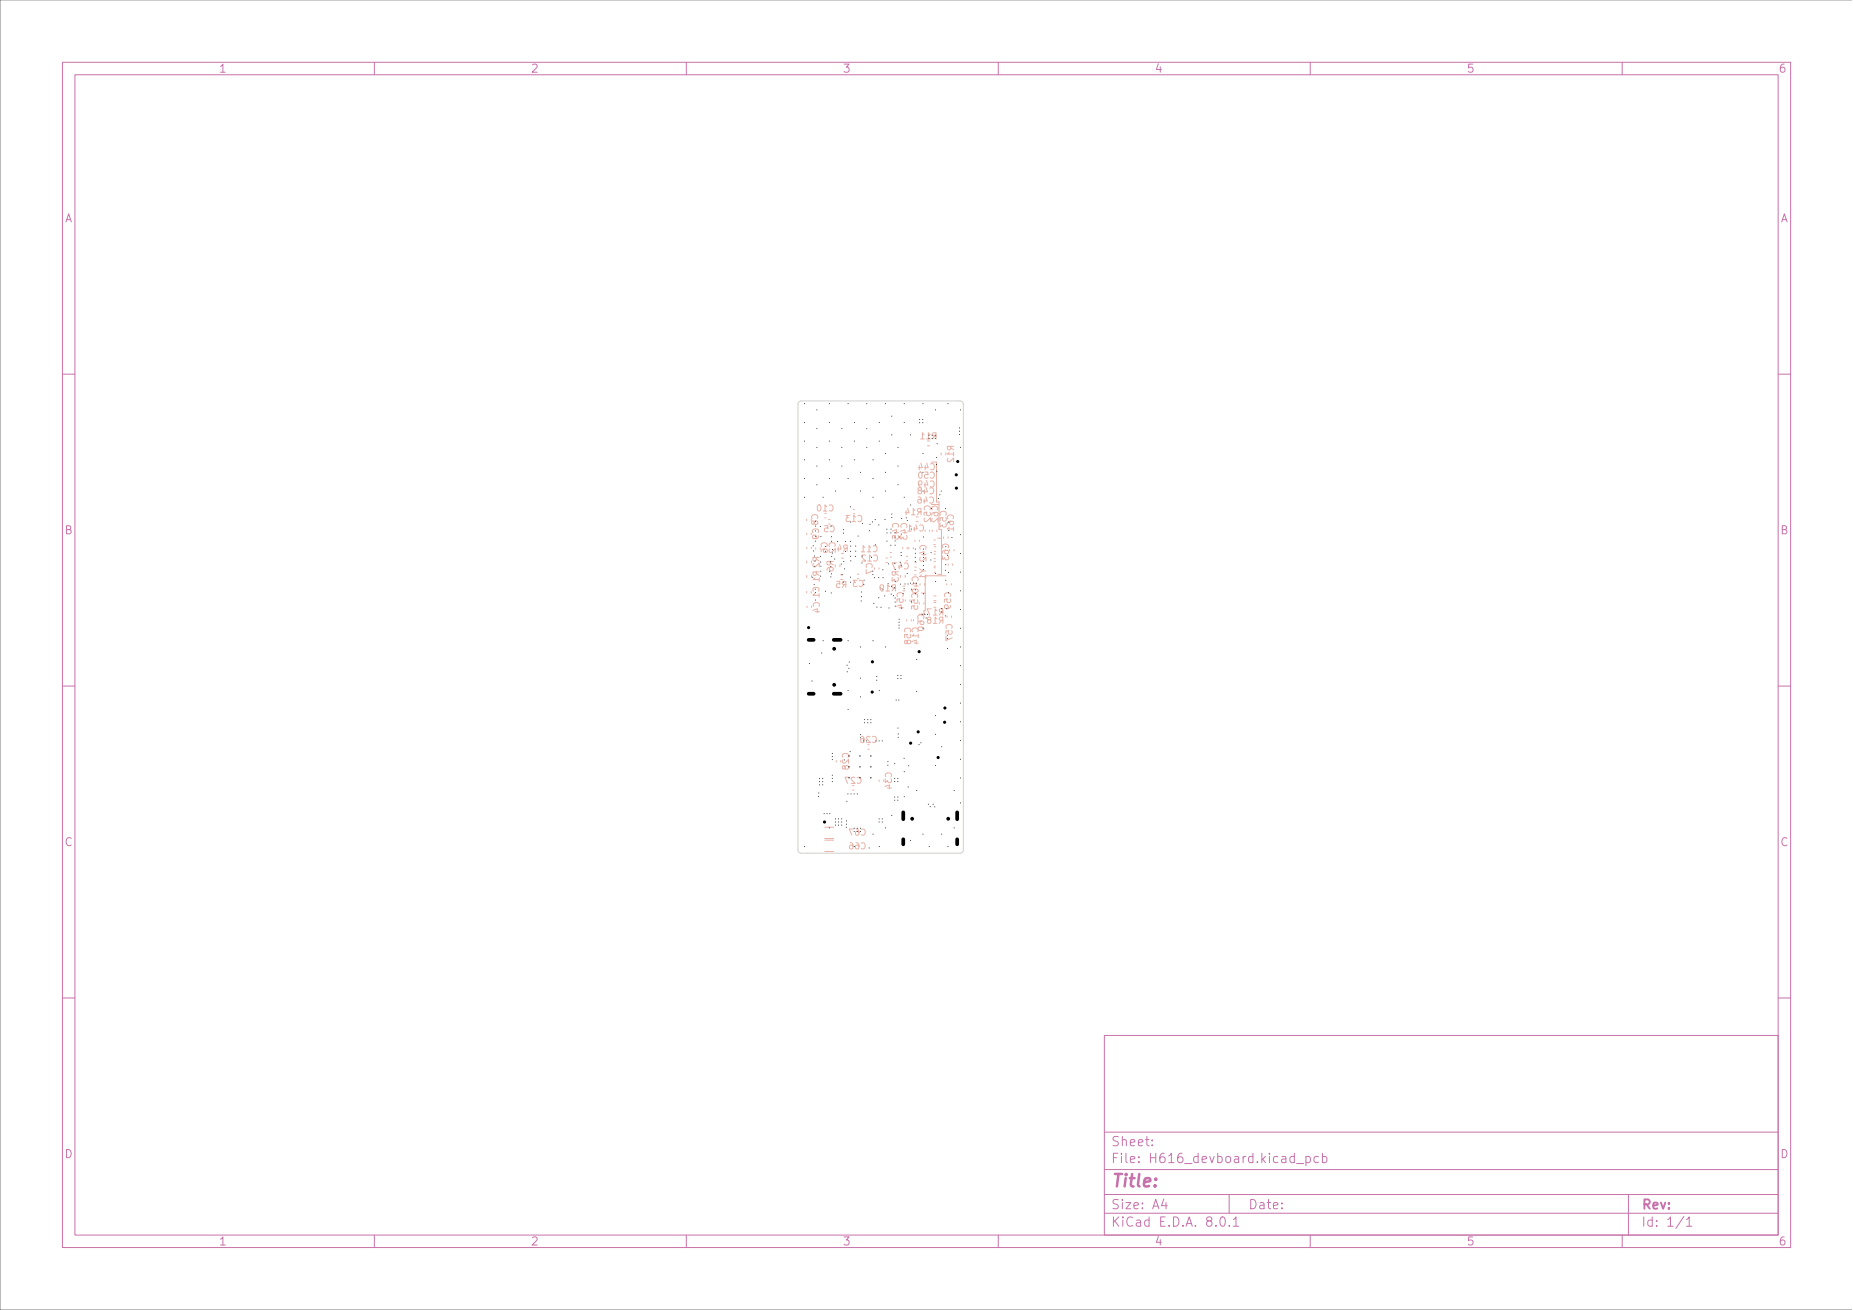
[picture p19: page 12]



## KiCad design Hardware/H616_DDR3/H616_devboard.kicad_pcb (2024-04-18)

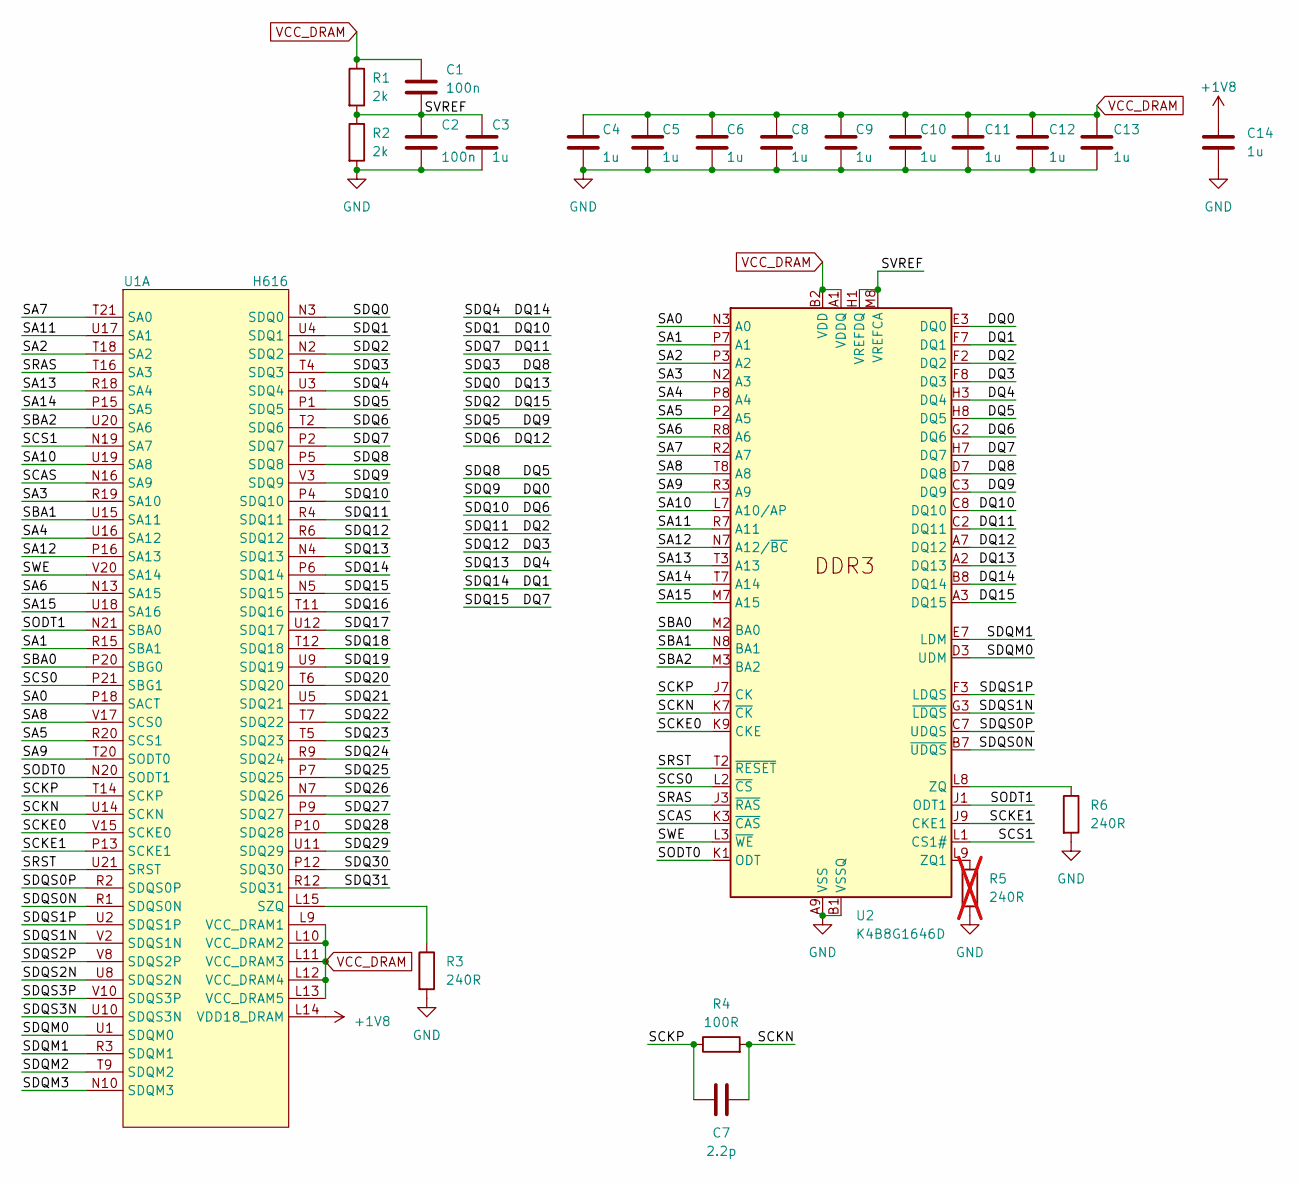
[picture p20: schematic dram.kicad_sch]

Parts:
C1, C2: 100n; C_0402_1005Metric_Pad0.74x0.62mm_HandSolder
C3, C4, C5, C6, C8, C9, C10, C11, C12, C13, C14: 1u; C_0402_1005Metric_Pad0.74x0.62mm_HandSolder
C7: 2.2p; C_0402_1005Metric_Pad0.74x0.62mm_HandSolder
R1, R2: 2k; R_0402_1005Metric_Pad0.72x0.64mm_HandSolder
R3, R6: 240R; R_0402_1005Metric_Pad0.72x0.64mm_HandSolder
R4: 100R; R_0402_1005Metric_Pad0.72x0.64mm_HandSolder
R5: 240R; R_0402_1005Metric_Pad0.72x0.64mm_HandSolder; not fitted
U1: H616; H616_TFBGA284
U2: K4B8G1646D; BGA-96_9.0x13.0mm_Layout2x3x16_P0.8mm

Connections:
+1V8: C14.1, U1.L14 (VDD18_DRAM); also elsewhere on the board
/DRAM/DQ0: U1.V3 (SDQ9), U2.E3 (DQ0)
/DRAM/DQ1: U1.P6 (SDQ14), U2.F7 (DQ1)
/DRAM/DQ2: U1.R4 (SDQ11), U2.F2 (DQ2)
/DRAM/DQ3: U1.R6 (SDQ12), U2.F8 (DQ3)
/DRAM/DQ4: U1.N4 (SDQ13), U2.H3 (DQ4)
/DRAM/DQ5: U1.P5 (SDQ8), U2.H8 (DQ5)
/DRAM/DQ6: U1.P4 (SDQ10), U2.G2 (DQ6)
/DRAM/DQ7: U1.N5 (SDQ15), U2.H7 (DQ7)
/DRAM/DQ8: U1.T4 (SDQ3), U2.D7 (DQ8)
/DRAM/DQ9: U1.P1 (SDQ5), U2.C3 (DQ9)
/DRAM/DQ10: U1.U4 (SDQ1), U2.C8 (DQ10)
/DRAM/DQ11: U1.P2 (SDQ7), U2.C2 (DQ11)
/DRAM/DQ12: U1.T2 (SDQ6), U2.A7 (DQ12)
/DRAM/DQ13: U1.N3 (SDQ0), U2.A2 (DQ13)
/DRAM/DQ14: U1.U3 (SDQ4), U2.B8 (DQ14)
/DRAM/DQ15: U1.N2 (SDQ2), U2.A3 (DQ15)
/DRAM/SA0: U1.P18 (SACT), U2.N3 (A0)
/DRAM/SA1: U1.R15 (SBA1), U2.P7 (A1)
/DRAM/SA2: U1.T18 (SA2), U2.P3 (A2)
/DRAM/SA3: U1.R19 (SA10), U2.N2 (A3)
/DRAM/SA4: U1.U16 (SA12), U2.P8 (A4)
/DRAM/SA5: U1.R20 (SCS1), U2.P2 (A5)
/DRAM/SA6: U1.N13 (SA15), U2.R8 (A6)
/DRAM/SA7: U1.T21 (SA0), U2.R2 (A7)
/DRAM/SA8: U1.V17 (SCS0), U2.T8 (A8)
/DRAM/SA9: U1.T20 (SODT0), U2.R3 (A9)
/DRAM/SA10: U1.U19 (SA8), U2.L7 (A10/AP)
/DRAM/SA11: U1.U17 (SA1), U2.R7 (A11)
/DRAM/SA12: U1.P16 (SA13), U2.N7 (A12/~BC)
/DRAM/SA13: U1.R18 (SA4), U2.T3 (A13)
/DRAM/SA14: U1.P15 (SA5), U2.T7 (A14)
/DRAM/SA15: U1.U18 (SA16), U2.M7 (A15)
/DRAM/SBA0: U1.P20 (SBG0), U2.M2 (BA0)
/DRAM/SBA1: U1.U15 (SA11), U2.N8 (BA1)
/DRAM/SBA2: U1.U20 (SA6), U2.M3 (BA2)
/DRAM/SCAS: U1.N16 (SA9), U2.K3 (~CAS)
/DRAM/SCKE0: U1.V15 (SCKE0), U2.K9 (CKE)
/DRAM/SCKE1: U1.P13 (SCKE1), U2.J9 (CKE1)
/DRAM/SCKN: C7.2, R4.2, U1.U14 (SCKN), U2.K7 (~CK)
/DRAM/SCKP: C7.1, R4.1, U1.T14 (SCKP), U2.J7 (CK)
/DRAM/SCS0: U1.P21 (SBG1), U2.L2 (~CS)
/DRAM/SCS1: U1.N19 (SA7), U2.L1 (CS1#)
/DRAM/SDQ16: U1.T11 (SDQ16)
/DRAM/SDQ17: U1.U12 (SDQ17)
/DRAM/SDQ18: U1.T12 (SDQ18)
/DRAM/SDQ19: U1.U9 (SDQ19)
/DRAM/SDQ20: U1.T6 (SDQ20)
/DRAM/SDQ21: U1.U5 (SDQ21)
/DRAM/SDQ22: U1.T7 (SDQ22)
/DRAM/SDQ23: U1.T5 (SDQ23)
/DRAM/SDQ24: U1.R9 (SDQ24)
/DRAM/SDQ25: U1.P7 (SDQ25)
/DRAM/SDQ26: U1.N7 (SDQ26)
/DRAM/SDQ27: U1.P9 (SDQ27)
/DRAM/SDQ28: U1.P10 (SDQ28)
/DRAM/SDQ29: U1.U11 (SDQ29)
/DRAM/SDQ30: U1.P12 (SDQ30)
/DRAM/SDQ31: U1.R12 (SDQ31)
/DRAM/SDQM0: U1.U1 (SDQM0), U2.D3 (UDM)
/DRAM/SDQM1: U1.R3 (SDQM1), U2.E7 (LDM)
/DRAM/SDQM2: U1.T9 (SDQM2)
/DRAM/SDQM3: U1.N10 (SDQM3)
/DRAM/SDQS0N: U1.R1 (SDQS0N), U2.B7 (~UDQS)
/DRAM/SDQS0P: U1.R2 (SDQS0P), U2.C7 (UDQS)
/DRAM/SDQS1N: U1.V2 (SDQS1N), U2.G3 (~LDQS)
/DRAM/SDQS1P: U1.U2 (SDQS1P), U2.F3 (LDQS)
/DRAM/SDQS2N: U1.U8 (SDQS2N)
/DRAM/SDQS2P: U1.V8 (SDQS2P)
/DRAM/SDQS3N: U1.U10 (SDQS3N)
/DRAM/SDQS3P: U1.V10 (SDQS3P)
/DRAM/SODT0: U1.N20 (SODT1), U2.K1 (ODT)
/DRAM/SODT1: U1.N21 (SBA0), U2.J1 (ODT1)
/DRAM/SRAS: U1.T16 (SA3), U2.J3 (~RAS)
/DRAM/SRST: U1.U21 (SRST), U2.T2 (~RESET)
/DRAM/SVREF: C1.2, C2.1, C3.1, R1.2, R2.1, U2.H1 (VREFDQ), U2.M8 (VREFCA)
/DRAM/SWE: U1.V20 (SA14), U2.L3 (~WE)
GND: C2.2, C3.2, C4.2, C5.2, C6.2, C8.2, C9.2, C10.2, C11.2, C12.2, C13.2, C14.2, R2.2, R3.2, R5.2, R6.2, U2.A9 (VSS), U2.B1 (VSSQ), U2.B3 (VSS), U2.B9 (VSSQ), U2.D1 (VSSQ), U2.D8 (VSSQ), U2.E1 (VSS), U2.E2 (VSSQ), U2.E8 (VSSQ), U2.F9 (VSSQ), U2.G1 (VSSQ), U2.G8 (VSS), U2.G9 (VSSQ), U2.J2 (VSS), U2.J8 (VSS), U2.M1 (VSS), U2.M9 (VSS), U2.P1 (VSS), U2.P9 (VSS), U2.T1 (VSS), U2.T9 (VSS); also elsewhere on the board
unnamed: R3.1, U1.L15 (SZQ)
unnamed: R5.1, U2.L9 (ZQ1)
unnamed: R6.1, U2.L8 (ZQ)
VCC_DRAM: C1.1, C4.1, C5.1, C6.1, C8.1, C9.1, C10.1, C11.1, C12.1, C13.1, R1.1, U1.L9 (VCC_DRAM1), U1.L10 (VCC_DRAM2), U1.L11 (VCC_DRAM3), U1.L12 (VCC_DRAM4), U1.L13 (VCC_DRAM5), U2.A1 (VDDQ), U2.A8 (VDDQ), U2.B2 (VDD), U2.C1 (VDDQ), U2.C9 (VDDQ), U2.D2 (VDDQ), U2.D9 (VDD), U2.E9 (VDDQ), U2.F1 (VDDQ), U2.G7 (VDD), U2.H2 (VDDQ), U2.H9 (VDDQ), U2.K2 (VDD), U2.K8 (VDD), U2.N1 (VDD), U2.N9 (VDD), U2.R1 (VDD), U2.R9 (VDD); also elsewhere on the board

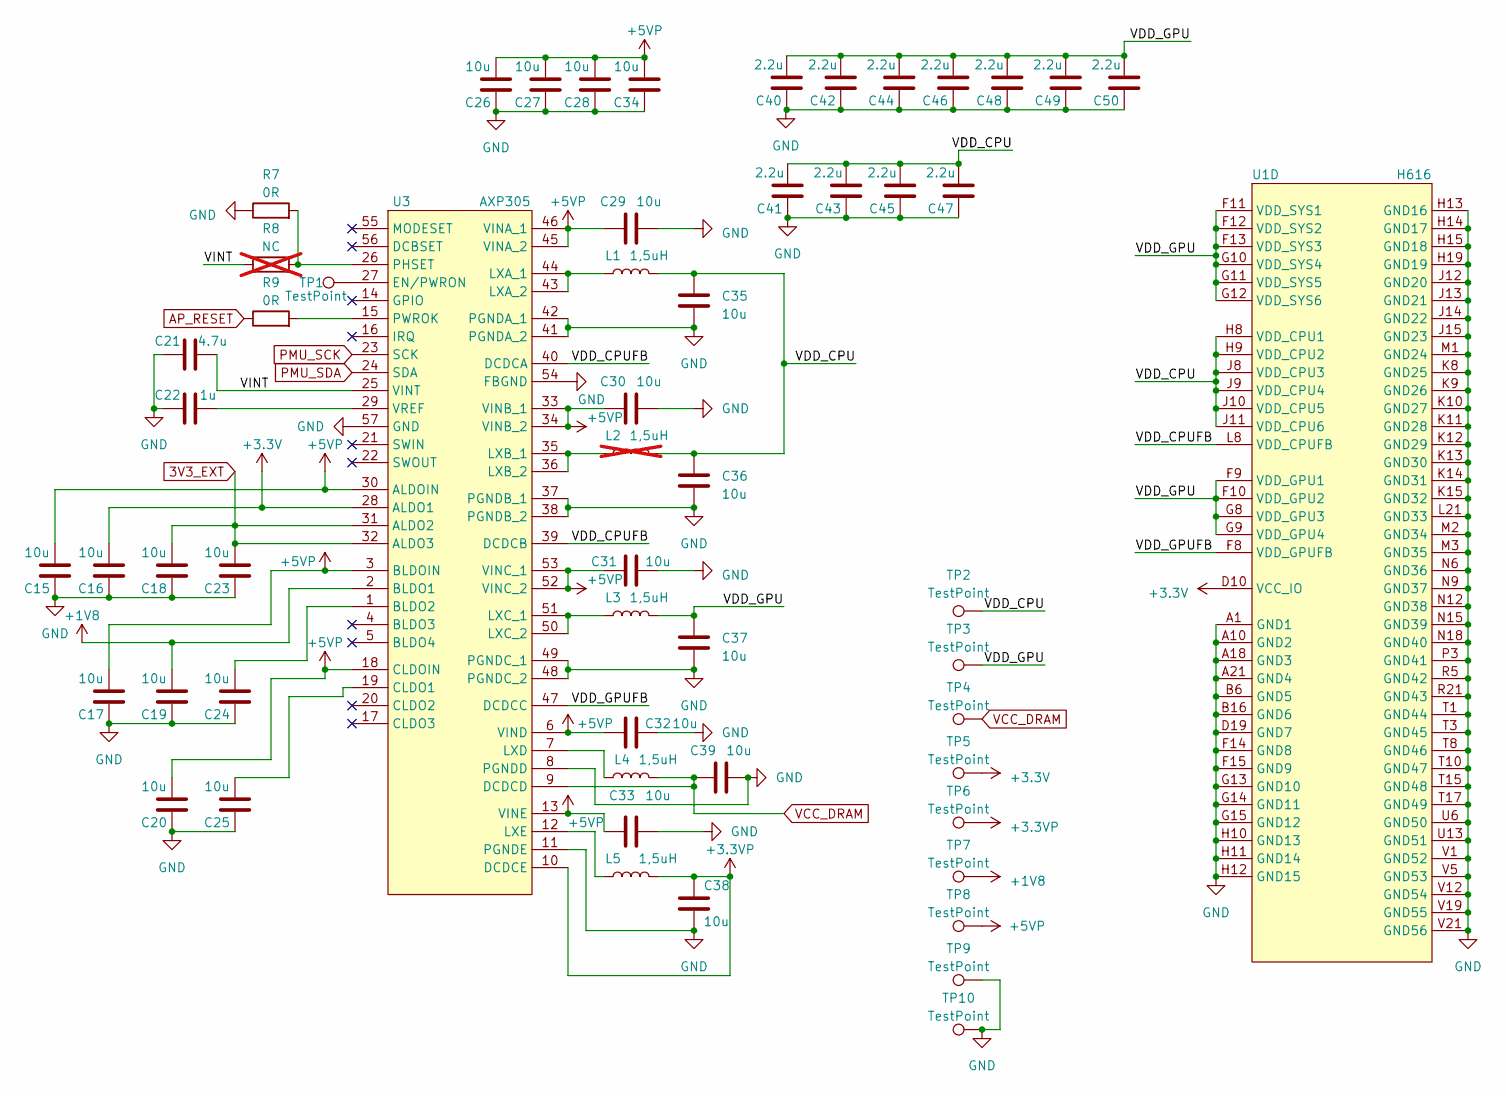
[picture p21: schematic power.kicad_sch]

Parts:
C15, C16, C17, C18, C19, C20, C23, C24, C25, C26, C27, C28, C29, C30, C31, C32, C33, C34, C35, C36, C37, C38, C39: 10u; C_0402_1005Metric_Pad0.74x0.62mm_HandSolder
C21: 4.7u; C_0402_1005Metric_Pad0.74x0.62mm_HandSolder
C22: 1u; C_0402_1005Metric_Pad0.74x0.62mm_HandSolder
C40, C41, C42, C43, C44, C45, C46, C47, C48, C49, C50: 2.2u; C_0402_1005Metric_Pad0.74x0.62mm_HandSolder
L1, L3, L4, L5: 1,5uH; L_Changjiang_FNR252010S
L2: 1,5uH; L_Changjiang_FNR252010S; not fitted
R7, R9: 0R; R_0402_1005Metric_Pad0.72x0.64mm_HandSolder
R8: NC; R_0402_1005Metric_Pad0.72x0.64mm_HandSolder; not fitted
TP1, TP2, TP3, TP4, TP5, TP6, TP7, TP8, TP9, TP10: TestPoint; TestPoint_THTPad_D1.0mm_Drill0.5mm
U1: H616; H616_TFBGA284
U3: AXP305; QFN-56-1EP_7x7mm_P0.4mm_EP4x4mm_ThermalVias

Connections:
3V3_EXT: C18.2, C23.2, U3.31 (ALDO2), U3.32 (ALDO3)
+1V8: C19.2, TP7.1, U3.2 (BLDO1); also elsewhere on the board
+3.3V: C16.2, TP5.1, U1.D10 (VCC_IO), U3.28 (ALDO1); also elsewhere on the board
+3.3VP: C38.2, L5.2, TP6.1, U3.10 (DCDCE)
+5VP: C15.2, C17.2, C20.2, C26.2, C27.2, C28.2, C29.1, C30.1, C31.1, C32.1, C33.1, C34.2, TP8.1, U3.3 (BLDOIN), U3.6 (VIND), U3.13 (VINE), U3.18 (CLDOIN), U3.30 (ALDOIN), U3.33 (VINB_1), U3.34 (VINB_2), U3.45 (VINA_2), U3.46 (VINA_1), U3.52 (VINC_2), U3.53 (VINC_1); also elsewhere on the board
/POWER/VDD_CPU: C35.1, C36.1, C41.2, C43.2, C45.2, C47.2, L1.2, L2.2, TP2.1, U1.H8 (VDD_CPU1), U1.H9 (VDD_CPU2), U1.J8 (VDD_CPU3), U1.J9 (VDD_CPU4), U1.J10 (VDD_CPU5), U1.J11 (VDD_CPU6)
/POWER/VDD_CPUFB: U1.L8 (VDD_CPUFB), U3.39 (DCDCB), U3.40 (DCDCA)
/POWER/VDD_GPU: C37.1, C40.2, C42.2, C44.2, C46.2, C48.2, C49.2, C50.2, L3.2, TP3.1, U1.F9 (VDD_GPU1), U1.F10 (VDD_GPU2), U1.F11 (VDD_SYS1), U1.F12 (VDD_SYS2), U1.F13 (VDD_SYS3), U1.G8 (VDD_GPU3), U1.G9 (VDD_GPU4), U1.G10 (VDD_SYS4), U1.G11 (VDD_SYS5), U1.G12 (VDD_SYS6)
/POWER/VDD_GPUFB: U1.F8 (VDD_GPUFB), U3.47 (DCDCC)
/POWER/VINT: C21.2, R8.1, U3.25 (VINT)
AP_RESET: R9.1; also elsewhere on the board
GND: C15.1, C16.1, C17.1, C18.1, C19.1, C20.1, C21.1, C22.1, C23.1, C24.1, C25.1, C26.1, C27.1, C28.1, C29.2, C30.2, C31.2, C32.2, C33.2, C34.1, C35.2, C36.2, C37.2, C38.1, C39.2, C40.1, C41.1, C42.1, C43.1, C44.1, C45.1, C46.1, C47.1, C48.1, C49.1, C50.1, R7.1, TP9.1, TP10.1, U1.A1 (GND1), U1.A10 (GND2), U1.A18 (GND3), U1.A21 (GND4), U1.B6 (GND5), U1.B16 (GND6), U1.D19 (GND7), U1.F14 (GND8), U1.F15 (GND9), U1.G13 (GND10), U1.G14 (GND11), U1.G15 (GND12), U1.H10 (GND13), U1.H11 (GND14), U1.H12 (GND15), U1.H13 (GND16), U1.H14 (GND17), U1.H15 (GND18), U1.H19 (GND19), U1.J12 (GND20), U1.J13 (GND21), U1.J14 (GND22), U1.J15 (GND23), U1.K8 (GND25), U1.K9 (GND26), U1.K10 (GND27), U1.K11 (GND28), U1.K12 (GND29), U1.K13 (GND30), U1.K14 (GND31), U1.K15 (GND32), U1.L21 (GND33), U1.M1 (GND24), U1.M2 (GND34), U1.M3 (GND35), U1.N6 (GND36), U1.N9 (GND37), U1.N12 (GND38), U1.N15 (GND39), U1.N18 (GND40), U1.P3 (GND41), U1.R5 (GND42), U1.R21 (GND43), U1.T1 (GND44), U1.T3 (GND45), U1.T8 (GND46), U1.T10 (GND47), U1.T15 (GND48), U1.T17 (GND49), U1.U6 (GND50), U1.U13 (GND51), U1.V1 (GND52), U1.V5 (GND53), U1.V12 (GND54), U1.V19 (GND55), U1.V21 (GND56), U3.8 (PGNDD), U3.11 (PGNDE), U3.37 (PGNDB_1), U3.38 (PGNDB_2), U3.41 (PGNDA_2), U3.42 (PGNDA_1), U3.48 (PGNDC_2), U3.49 (PGNDC_1), U3.54 (FBGND), U3.57 (GND); also elsewhere on the board
unnamed: C24.2, U3.1 (BLDO2)
unnamed: C25.2, U3.19 (CLDO1)
unnamed: TP1.1, U3.27 (EN/PWRON)
unnamed: L1.1, U3.43 (LXA_2), U3.44 (LXA_1)
unnamed: L2.1, U3.35 (LXB_1), U3.36 (LXB_2)
unnamed: L3.1, U3.50 (LXC_2), U3.51 (LXC_1)
unnamed: L4.1, U3.7 (LXD)
unnamed: L5.1, U3.12 (LXE)
unnamed: R7.2, R8.2, U3.26 (PHSET)
unnamed: R9.2, U3.15 (PWROK)
unnamed: C22.2, U3.29 (VREF)
PMU_SCK: U3.23 (SCK); also elsewhere on the board
PMU_SDA: U3.24 (SDA); also elsewhere on the board
VCC_DRAM: C39.1, L4.2, TP4.1, U3.9 (DCDCD); also elsewhere on the board

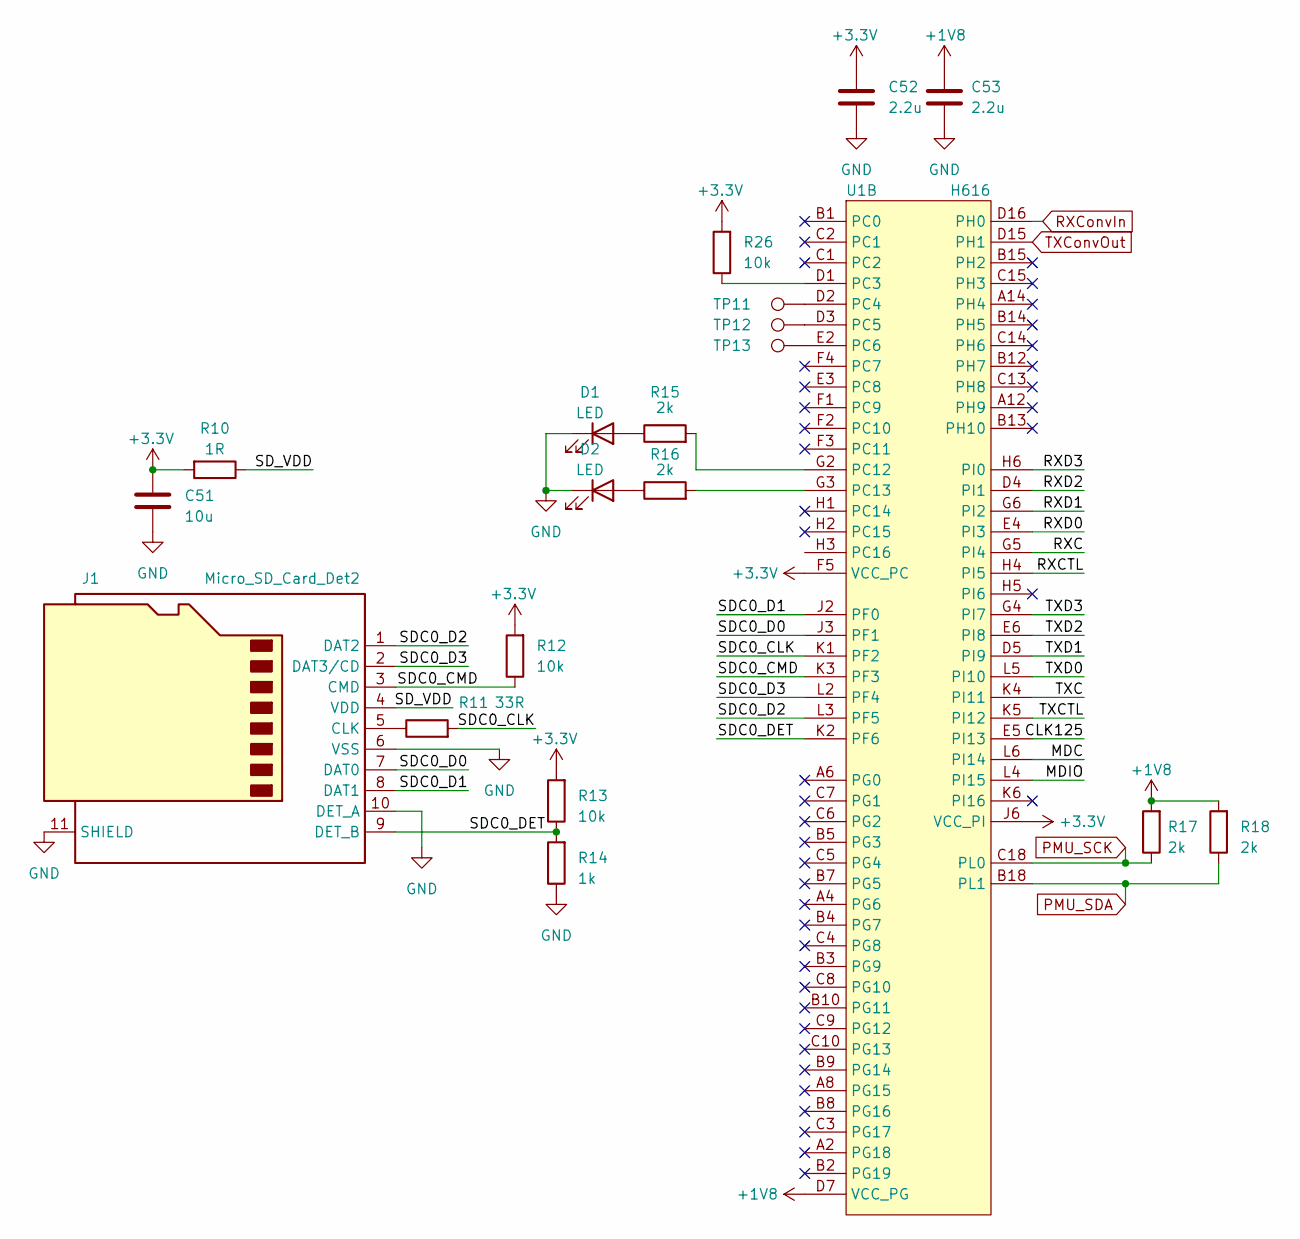
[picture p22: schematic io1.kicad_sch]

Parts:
C51: 10u; C_0402_1005Metric_Pad0.74x0.62mm_HandSolder
C52, C53: 2.2u; C_0402_1005Metric_Pad0.74x0.62mm_HandSolder
D1, D2: LED; LED_0603_1608Metric_Pad1.05x0.95mm_HandSolder
J1: Micro_SD_Card_Det2; microSD_HC_Hirose_DM3AT-SF-PEJM5
R10: 1R; R_0402_1005Metric_Pad0.72x0.64mm_HandSolder
R11: 33R; R_0402_1005Metric_Pad0.72x0.64mm_HandSolder
R12, R13, R26: 10k; R_0402_1005Metric_Pad0.72x0.64mm_HandSolder
R14: 1k; R_0402_1005Metric_Pad0.72x0.64mm_HandSolder
R15, R16, R17, R18: 2k; R_0402_1005Metric_Pad0.72x0.64mm_HandSolder
TP11, TP12, TP13: TestPoint; TestPoint_THTPad_D1.0mm_Drill0.5mm
U1: H616; H616_TFBGA284

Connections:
+1V8: C53.1, R17.2, R18.2, U1.D7 (VCC_PG); also elsewhere on the board
+3.3V: C51.1, C52.1, R10.2, R12.2, R13.2, R26.2, U1.F5 (VCC_PC), U1.J6 (VCC_PI); also elsewhere on the board
/IO1/CLK125: U1.E5 (PI13)
/IO1/MDC: U1.L6 (PI14)
/IO1/MDIO: U1.L4 (PI15)
/IO1/RXC: U1.G5 (PI4)
/IO1/RXCTL: U1.H4 (PI5)
/IO1/RXD0: U1.E4 (PI3)
/IO1/RXD1: U1.G6 (PI2)
/IO1/RXD2: U1.D4 (PI1)
/IO1/RXD3: U1.H6 (PI0)
/IO1/SDC0_CLK: R11.2, U1.K1 (PF2)
/IO1/SDC0_CMD: J1.3 (CMD), R12.1, U1.K3 (PF3)
/IO1/SDC0_D0: J1.7 (DAT0), U1.J3 (PF1)
/IO1/SDC0_D1: J1.8 (DAT1), U1.J2 (PF0)
/IO1/SDC0_D2: J1.1 (DAT2), U1.L3 (PF5)
/IO1/SDC0_D3: J1.2 (DAT3/CD), U1.L2 (PF4)
/IO1/SDC0_DET: J1.9 (DET_B), R13.1, R14.2, U1.K2 (PF6)
/IO1/SD_VDD: J1.4 (VDD), R10.1
/IO1/TXC: U1.K4 (PI11)
/IO1/TXCTL: U1.K5 (PI12)
/IO1/TXD0: U1.L5 (PI10)
/IO1/TXD1: U1.D5 (PI9)
/IO1/TXD2: U1.E6 (PI8)
/IO1/TXD3: U1.G4 (PI7)
GND: C51.2, C52.2, C53.2, D1.1 (K), D2.1 (K), J1.6 (VSS), J1.10 (DET_A), J1.11 (SHIELD), R14.1; also elsewhere on the board
unnamed: D1.2 (A), R15.1
unnamed: D2.2 (A), R16.1
unnamed: J1.5 (CLK), R11.1
unnamed: R26.1, U1.D1 (PC3)
unnamed: TP11.1, U1.D2 (PC4)
unnamed: TP12.1, U1.D3 (PC5)
unnamed: TP13.1, U1.E2 (PC6)
unnamed: R15.2, U1.G2 (PC12)
unnamed: R16.2, U1.G3 (PC13)
PMU_SCK: R17.1, U1.C18 (PL0); also elsewhere on the board
PMU_SDA: R18.1, U1.B18 (PL1); also elsewhere on the board
RXConvIn: U1.D16 (PH0); also elsewhere on the board
TXConvOut: U1.D15 (PH1); also elsewhere on the board

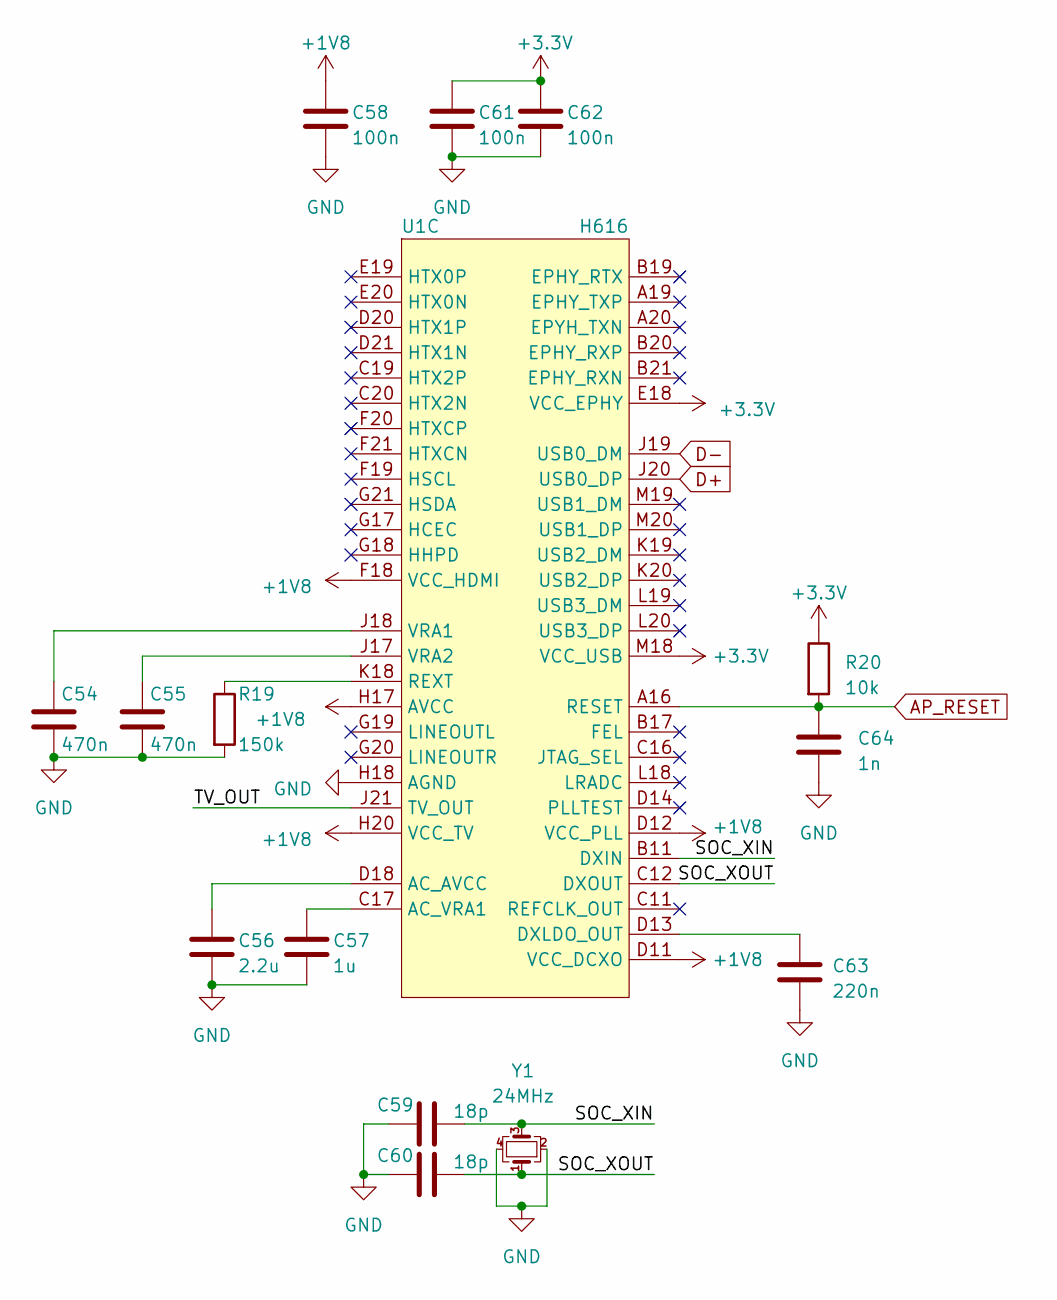
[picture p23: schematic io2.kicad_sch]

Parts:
C54, C55: 470n; C_0402_1005Metric_Pad0.74x0.62mm_HandSolder
C56: 2.2u; C_0402_1005Metric_Pad0.74x0.62mm_HandSolder
C57: 1u; C_0402_1005Metric_Pad0.74x0.62mm_HandSolder
C58, C61, C62: 100n; C_0402_1005Metric_Pad0.74x0.62mm_HandSolder
C59, C60: 18p; C_0402_1005Metric_Pad0.74x0.62mm_HandSolder
C63: 220n; C_0402_1005Metric_Pad0.74x0.62mm_HandSolder
C64: 1n; C_0402_1005Metric_Pad0.74x0.62mm_HandSolder
R19: 150k; R_0402_1005Metric_Pad0.72x0.64mm_HandSolder
R20: 10k; R_0402_1005Metric_Pad0.72x0.64mm_HandSolder
U1: H616; H616_TFBGA284
Y1: 24MHz; Crystal_SMD_2520-4Pin_2.5x2.0mm

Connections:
+1V8: C58.1, U1.D11 (VCC_DCXO), U1.D12 (VCC_PLL), U1.F18 (VCC_HDMI), U1.H17 (AVCC), U1.H20 (VCC_TV); also elsewhere on the board
+3.3V: C61.1, C62.1, R20.1, U1.E18 (VCC_EPHY), U1.M18 (VCC_USB); also elsewhere on the board
/IO2/SOC_XIN: C59.2, U1.B11 (DXIN), Y1.3
/IO2/SOC_XOUT: C60.2, U1.C12 (DXOUT), Y1.1
/IO2/TV_OUT: U1.J21 (TV_OUT)
AP_RESET: C64.1, R20.2, U1.A16 (RESET); also elsewhere on the board
D+: U1.J20 (USB0_DP); also elsewhere on the board
D-: U1.J19 (USB0_DM); also elsewhere on the board
GND: C54.2, C55.2, C56.2, C57.2, C58.2, C59.1, C60.1, C61.2, C62.2, C63.2, C64.2, R19.2, U1.H18 (AGND), Y1.2, Y1.4; also elsewhere on the board
unnamed: C56.1, U1.D18 (AC_AVCC)
unnamed: C57.1, U1.C17 (AC_VRA1)
unnamed: C63.1, U1.D13 (DXLDO_OUT)
unnamed: R19.1, U1.K18 (REXT)
unnamed: C54.1, U1.J18 (VRA1)
unnamed: C55.1, U1.J17 (VRA2)

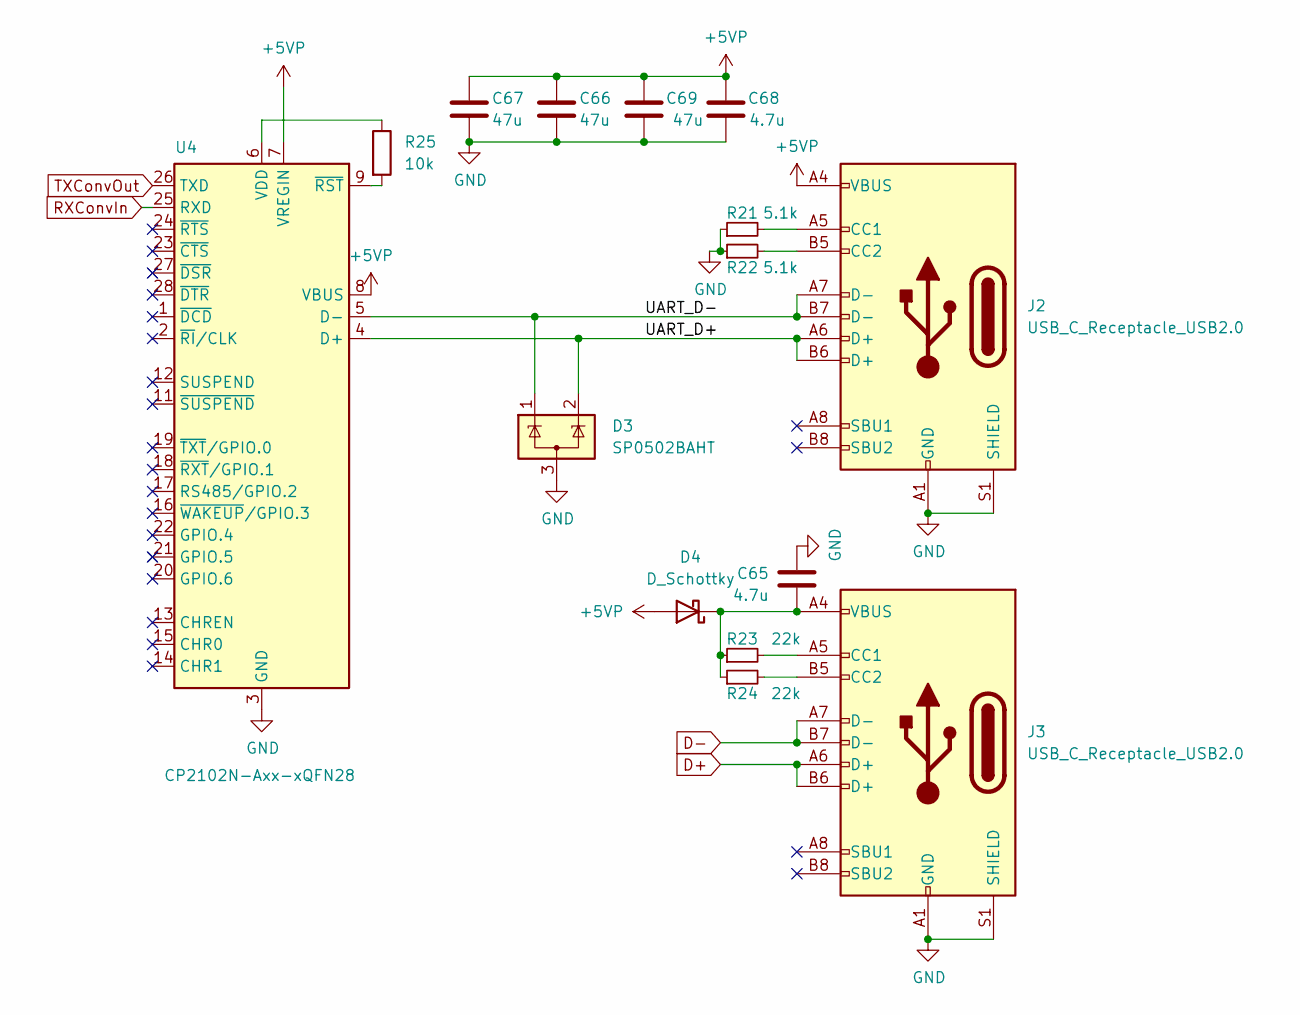
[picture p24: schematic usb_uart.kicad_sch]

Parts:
C65, C68: 4.7u; C_0402_1005Metric_Pad0.74x0.62mm_HandSolder
C66, C67, C69: 47u; C_1206_3216Metric_Pad1.33x1.80mm_HandSolder
D3: SP0502BAHT; SOT-23
D4: D_Schottky; D_SOD-323_HandSoldering
J2, J3: USB_C_Receptacle_USB2.0; USB_C_Receptacle_Palconn_UTC16-G
R21, R22: 5.1k; R_0402_1005Metric_Pad0.72x0.64mm_HandSolder
R23, R24: 22k; R_0402_1005Metric_Pad0.72x0.64mm_HandSolder
R25: 10k; R_0402_1005Metric_Pad0.72x0.64mm_HandSolder
U4: CP2102N-Axx-xQFN28; QFN-28-1EP_5x5mm_P0.5mm_EP3.35x3.35mm

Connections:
+5VP: C66.1, C67.1, C68.1, C69.1, D4.2 (A), J2.A4 (VBUS), J2.A9 (VBUS), J2.B4 (VBUS), J2.B9 (VBUS), U4.7 (VREGIN), U4.8 (VBUS); also elsewhere on the board
/USB-UART/UART_D+: D3.2 (K), J2.A6 (D+), J2.B6 (D+), U4.4 (D+)
/USB-UART/UART_D-: D3.1 (K), J2.A7 (D-), J2.B7 (D-), U4.5 (D-)
D+: J3.A6 (D+), J3.B6 (D+); also elsewhere on the board
D-: J3.A7 (D-), J3.B7 (D-); also elsewhere on the board
GND: C65.1, C66.2, C67.2, C68.2, C69.2, D3.3 (A), J2.A1 (GND), J2.A12 (GND), J2.B1 (GND), J2.B12 (GND), J2.S1 (SHIELD), J3.A1 (GND), J3.A12 (GND), J3.B1 (GND), J3.B12 (GND), J3.S1 (SHIELD), R21.1, R22.1, U4.3 (GND), U4.29 (GND); also elsewhere on the board
unnamed: C65.2, D4.1 (K), J3.A4 (VBUS), J3.A9 (VBUS), J3.B4 (VBUS), J3.B9 (VBUS), R23.1, R24.1
unnamed: J2.A5 (CC1), R21.2
unnamed: J2.B5 (CC2), R22.2
unnamed: J3.A5 (CC1), R23.2
unnamed: J3.B5 (CC2), R24.2
unnamed: R25.1, U4.6 (VDD)
unnamed: R25.2, U4.9 (~RST)
RXConvIn: U4.25 (RXD); also elsewhere on the board
TXConvOut: U4.26 (TXD); also elsewhere on the board

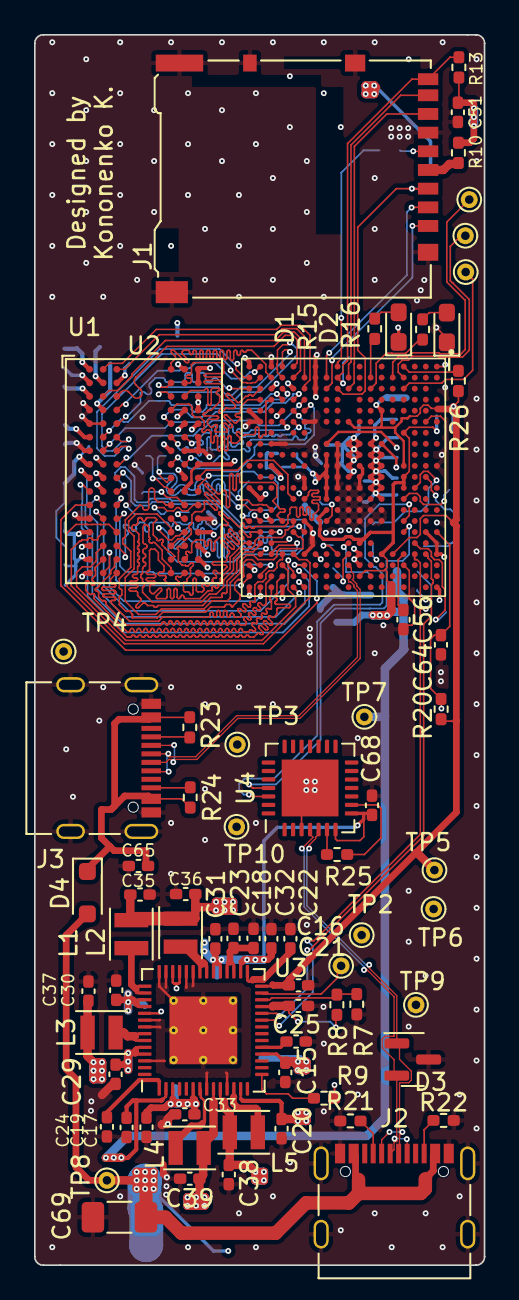
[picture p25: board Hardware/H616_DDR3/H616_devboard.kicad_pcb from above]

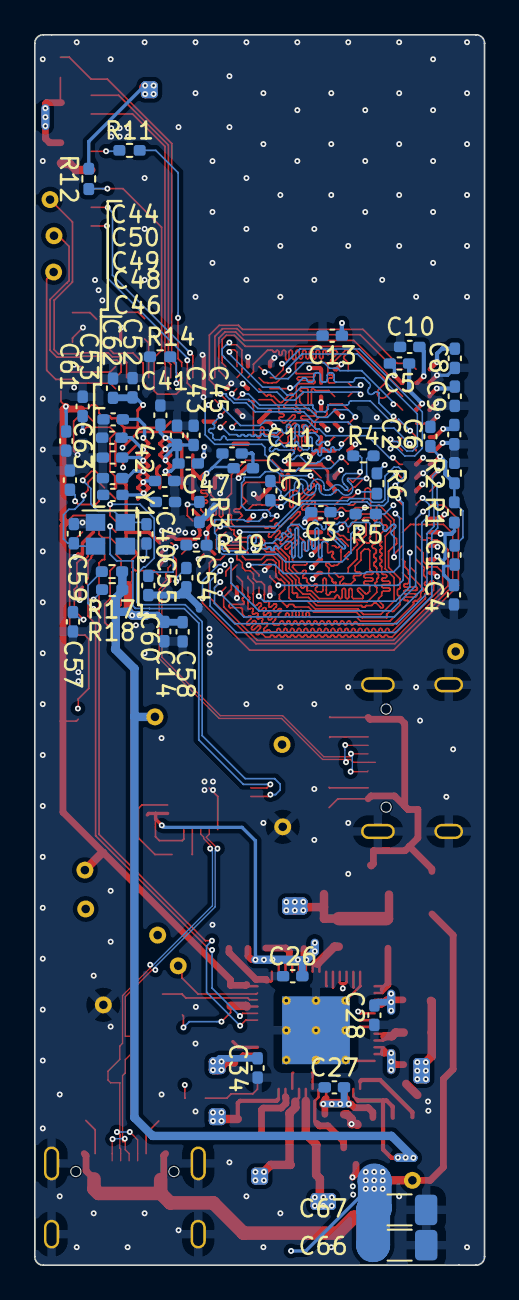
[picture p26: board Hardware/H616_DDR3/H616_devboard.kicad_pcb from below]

Board: 4 copper layers, 26.5 x 72.5 mm, 125 parts (55 on the bottom side), 121 nets.

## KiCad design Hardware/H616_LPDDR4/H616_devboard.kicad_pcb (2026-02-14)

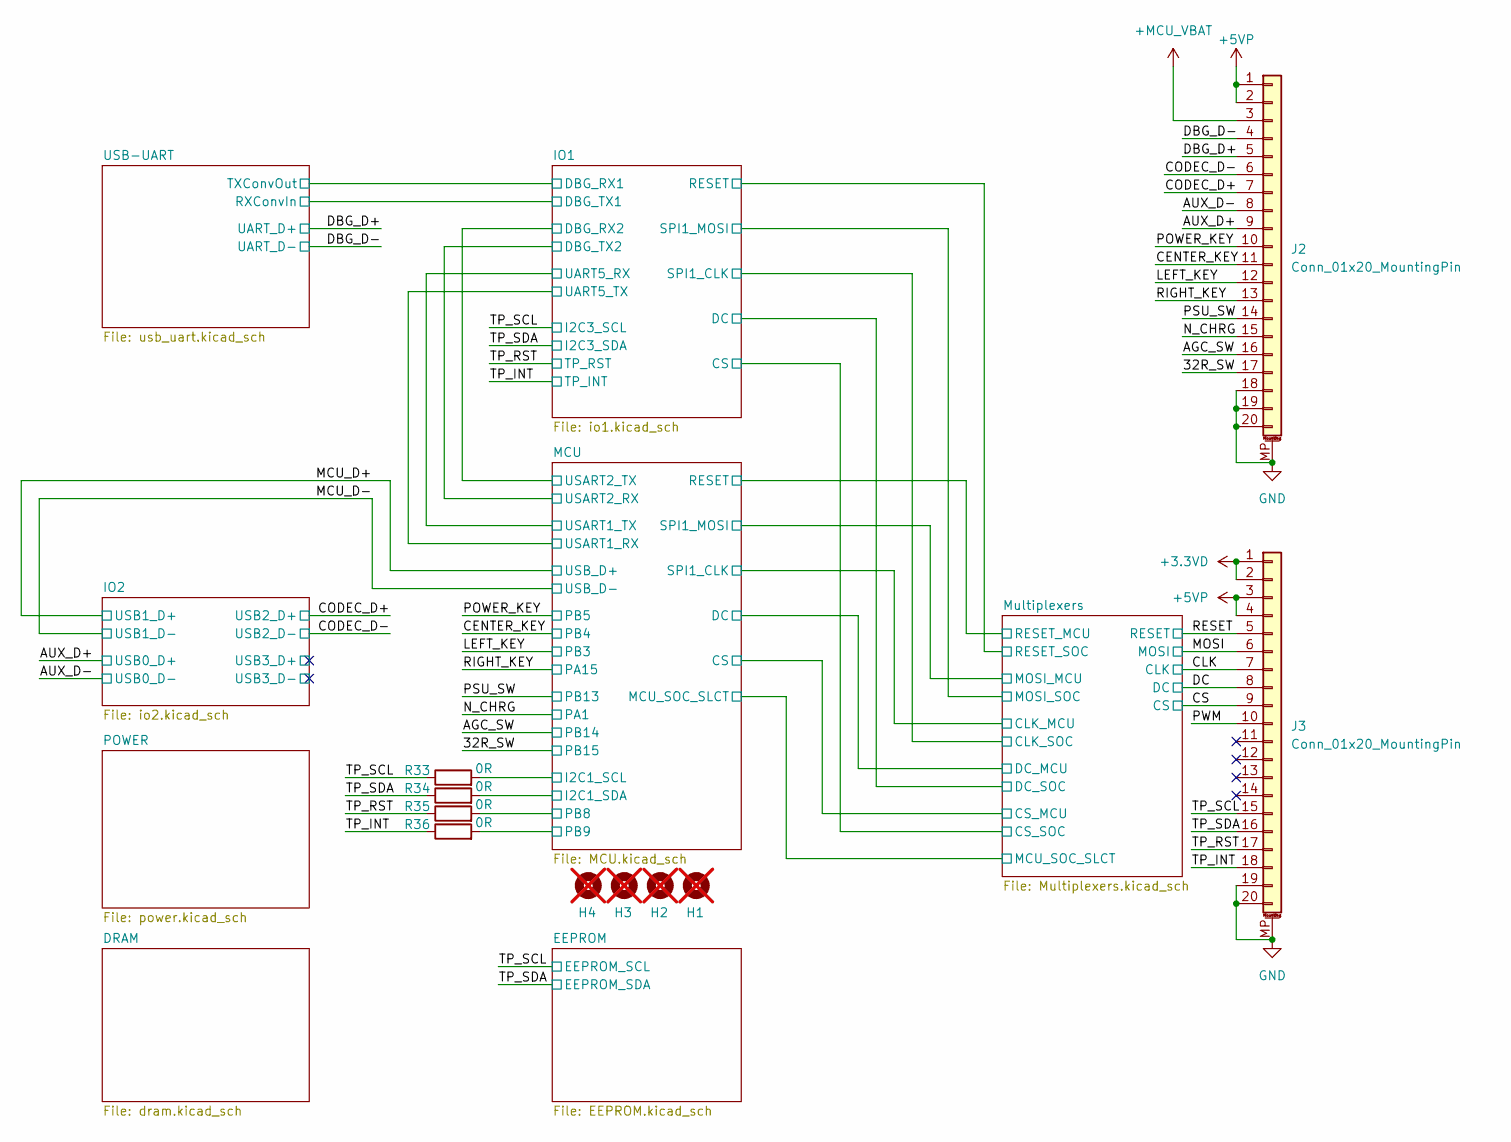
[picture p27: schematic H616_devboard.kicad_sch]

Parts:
H1, H2, H3, H4: MountingHole; MountingHole_3.2mm_M3_DIN965; not fitted
J2, J3: Conn_01x20_MountingPin; TE_2-84952-0_1x20-1MP_P1.0mm_Horizontal; Part Number XW10202-20R-00
R33, R34, R35, R36: 0R; R_0402_1005Metric_Pad0.72x0.64mm_HandSolder; Part Number RC0402FR-070RL

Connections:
+3.3VD: J3.1, J3.2; also elsewhere on the board
+5VP: J2.1, J2.2, J3.3, J3.4; also elsewhere on the board
+MCU_VBAT: J2.3; also elsewhere on the board
/32R_SW: J2.17; also elsewhere on the board
/AGC_SW: J2.16; also elsewhere on the board
/AUX_D+: J2.9; also elsewhere on the board
/AUX_D-: J2.8; also elsewhere on the board
/CENTER_KEY: J2.11; also elsewhere on the board
/CLK: J3.7; also elsewhere on the board
/CODEC_D+: J2.7; also elsewhere on the board
/CODEC_D-: J2.6; also elsewhere on the board
/CS: J3.9; also elsewhere on the board
/DBG_D+: J2.5; also elsewhere on the board
/DBG_D-: J2.4; also elsewhere on the board
/DC: J3.8; also elsewhere on the board
/LEFT_KEY: J2.12; also elsewhere on the board
/MCU/I2C1_SCL: R33.2; also elsewhere on the board
/MCU/I2C1_SDA: R34.2; also elsewhere on the board
/MCU/PB8: R35.2; also elsewhere on the board
/MCU/PB9: R36.2; also elsewhere on the board
/MOSI: J3.6; also elsewhere on the board
/N_CHRG: J2.15; also elsewhere on the board
/POWER_KEY: J2.10; also elsewhere on the board
/PSU_SW: J2.14; also elsewhere on the board
/PWM: J3.10
/RESET: J3.5; also elsewhere on the board
/RIGHT_KEY: J2.13; also elsewhere on the board
/TP_INT: J3.18, R36.1; also elsewhere on the board
/TP_RST: J3.17, R35.1; also elsewhere on the board
/TP_SCL: J3.15, R33.1; also elsewhere on the board
/TP_SDA: J3.16, R34.1; also elsewhere on the board
GND: J2.18, J2.19, J2.20, J2.MP (MountPin), J3.19, J3.20, J3.MP (MountPin); also elsewhere on the board

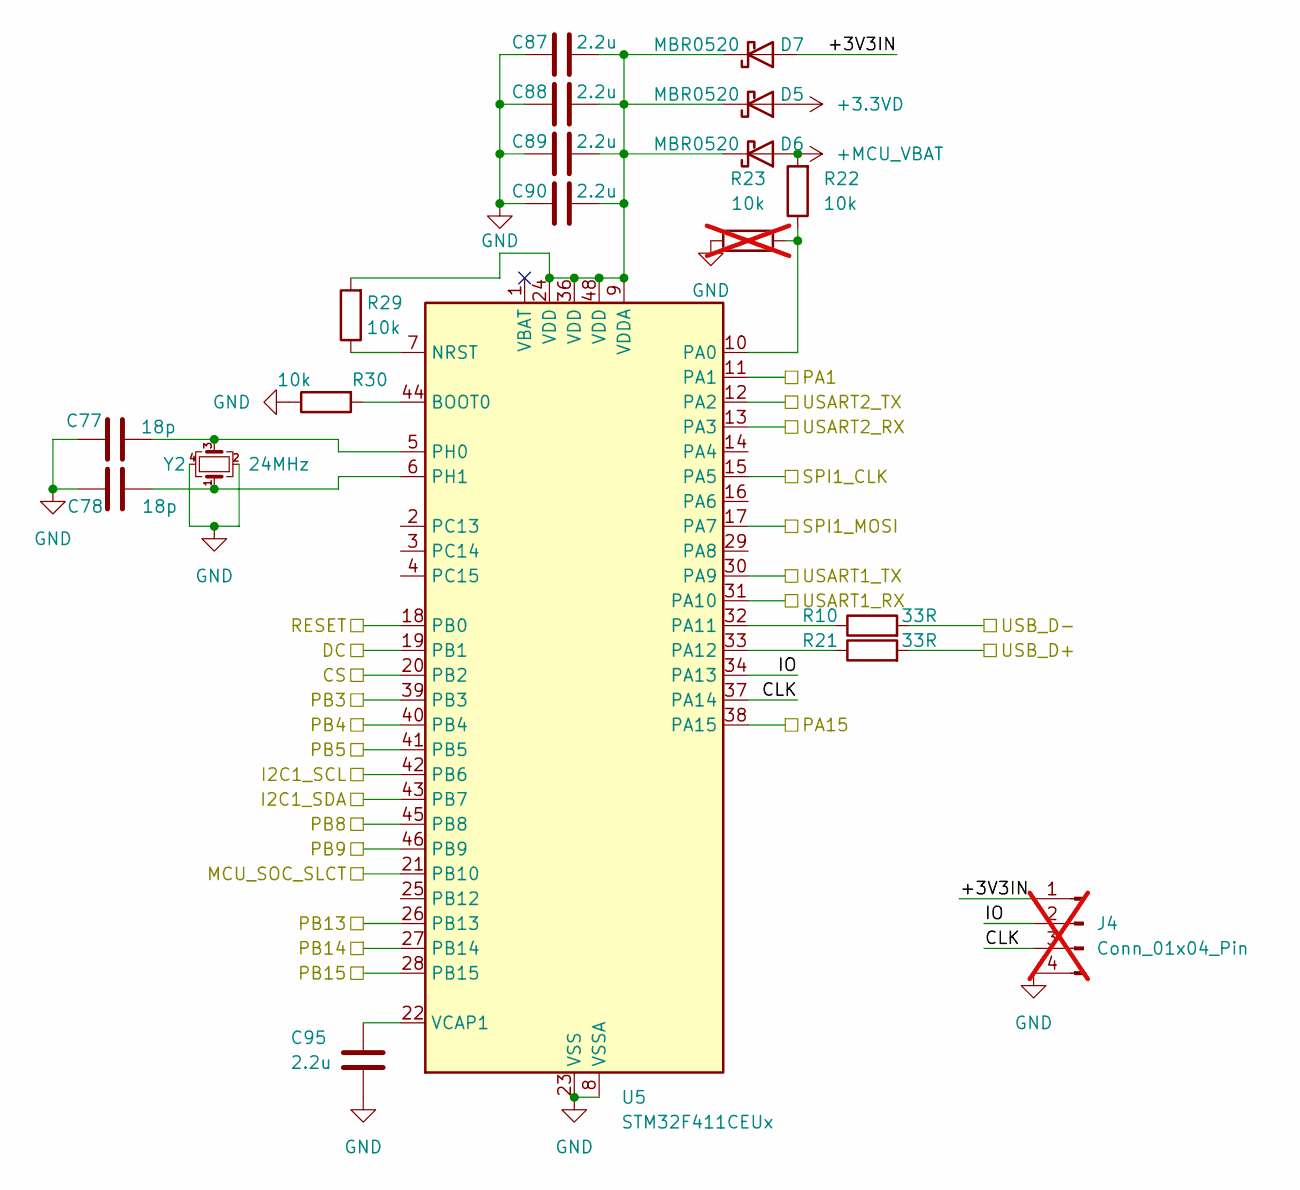
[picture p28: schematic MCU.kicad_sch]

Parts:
C77, C78: 18p; C_0402_1005Metric_Pad0.74x0.62mm_HandSolder; Part Number 0402CG180J500NT
C87, C88, C89, C90, C95: 2.2u; C_0402_1005Metric_Pad0.74x0.62mm_HandSolder; Part Number CL05A225KO5NQNC
D5, D6, D7: MBR0520; D_SOD-123; Part Number MBR0520
J4: Conn_01x04_Pin; PinHeader_1x04_P2.54mm_Vertical; not fitted
R10, R21: 33R; R_0402_1005Metric_Pad0.72x0.64mm_HandSolder; Part Number RC0402FR-0733RL
R22, R29, R30: 10k; R_0402_1005Metric_Pad0.72x0.64mm_HandSolder; Part Number RC0402FR-0710KL
R23: 10k; R_0402_1005Metric_Pad0.72x0.64mm_HandSolder; not fitted
U5: STM32F411CEUx; QFN-48-1EP_7x7mm_P0.5mm_EP5.6x5.6mm; Part Number STM32F411CEU6
Y2: 24MHz; Crystal_SMD_2520-4Pin_2.5x2.0mm; Part Number XTM25024000JT00351001

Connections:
+3.3VD: D5.2 (A); also elsewhere on the board
+MCU_VBAT: D6.2 (A), R22.2; also elsewhere on the board
/32R_SW: U5.28 (PB15); also elsewhere on the board
/AGC_SW: U5.27 (PB14); also elsewhere on the board
/CENTER_KEY: U5.40 (PB4); also elsewhere on the board
/IO1/DBG_RX2: U5.12 (PA2); also elsewhere on the board
/IO1/DBG_TX2: U5.13 (PA3); also elsewhere on the board
/IO1/UART5_RX: U5.30 (PA9); also elsewhere on the board
/IO1/UART5_TX: U5.31 (PA10); also elsewhere on the board
/LEFT_KEY: U5.39 (PB3); also elsewhere on the board
/MCU/+3V3IN: D7.2 (A), J4.1
/MCU/CLK: J4.3, U5.37 (PA14)
/MCU/CS: U5.20 (PB2); also elsewhere on the board
/MCU/DC: U5.19 (PB1); also elsewhere on the board
/MCU/I2C1_SCL: U5.42 (PB6); also elsewhere on the board
/MCU/I2C1_SDA: U5.43 (PB7); also elsewhere on the board
/MCU/IO: J4.2, U5.34 (PA13)
/MCU/MCU_SOC_SLCT: U5.21 (PB10); also elsewhere on the board
/MCU/PB8: U5.45 (PB8); also elsewhere on the board
/MCU/PB9: U5.46 (PB9); also elsewhere on the board
/MCU/RESET: U5.18 (PB0); also elsewhere on the board
/MCU/SPI1_CLK: U5.15 (PA5); also elsewhere on the board
/MCU/SPI1_MOSI: U5.17 (PA7); also elsewhere on the board
/MCU_D+: R21.2; also elsewhere on the board
/MCU_D-: R10.2; also elsewhere on the board
/N_CHRG: U5.11 (PA1); also elsewhere on the board
/POWER_KEY: U5.41 (PB5); also elsewhere on the board
/PSU_SW: U5.26 (PB13); also elsewhere on the board
/RIGHT_KEY: U5.38 (PA15); also elsewhere on the board
GND: C77.1, C78.1, C87.1, C88.1, C89.1, C90.1, C95.1, J4.4, R23.1, R30.1, U5.8 (VSSA), U5.23 (VSS), U5.35 (VSS), U5.47 (VSS), U5.49 (VSS), Y2.2, Y2.4; also elsewhere on the board
unnamed: C87.2, C88.2, C89.2, C90.2, D5.1 (K), D6.1 (K), D7.1 (K), R29.2, U5.9 (VDDA), U5.24 (VDD), U5.36 (VDD), U5.48 (VDD)
unnamed: R30.2, U5.44 (BOOT0)
unnamed: R29.1, U5.7 (NRST)
unnamed: R22.1, R23.2, U5.10 (PA0)
unnamed: R10.1, U5.32 (PA11)
unnamed: R21.1, U5.33 (PA12)
unnamed: C77.2, U5.5 (PH0), Y2.3
unnamed: C78.2, U5.6 (PH1), Y2.1
unnamed: C95.2, U5.22 (VCAP1)

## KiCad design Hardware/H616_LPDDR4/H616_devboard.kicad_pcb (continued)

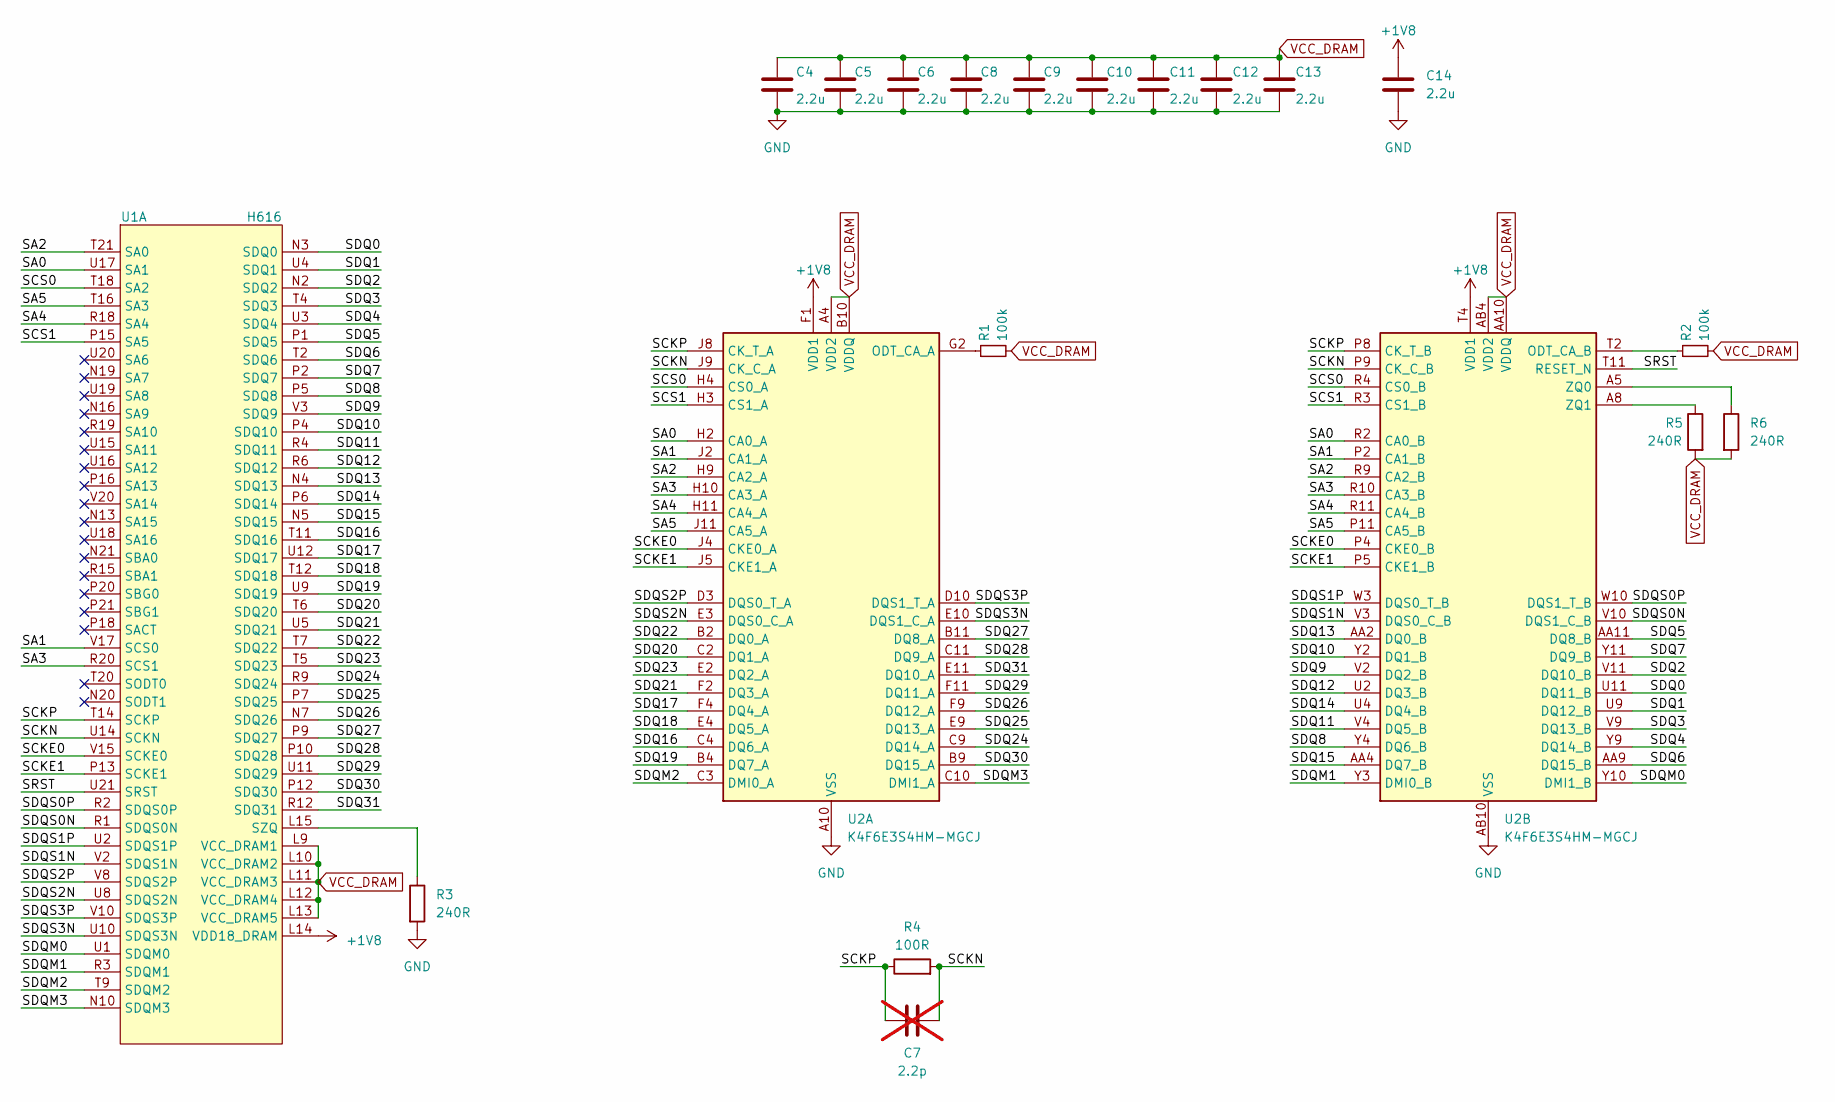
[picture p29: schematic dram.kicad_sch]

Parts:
C4, C5, C6, C8, C9, C10, C11, C12, C13, C14: 2.2u; C_0402_1005Metric_Pad0.74x0.62mm_HandSolder; Part Number CL05A225KO5NQNC
C7: 2.2p; C_0402_1005Metric_Pad0.74x0.62mm_HandSolder; not fitted
R1, R2: 100k; R_0402_1005Metric_Pad0.72x0.64mm_HandSolder; Part Number RC0402FR-07100KL
R3, R5, R6: 240R; R_0402_1005Metric_Pad0.72x0.64mm_HandSolder; Part Number RC0402FR-07240RL
R4: 100R; R_0402_1005Metric_Pad0.72x0.64mm_HandSolder; Part Number RC0402FR-07100RL
U1: H616; H616_TFBGA284; Part Number H616
U2: IS43LQ32256A-062BLI; BGA-200_10.0x14.5mm_Layout12x22_P0.80x0.65mm; Part Number K4F6E3S4HM-MGCJ

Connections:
+1V8: C14.1, U1.L14 (VDD18_DRAM), U2.F1 (VDD1), U2.F12 (VDD1), U2.G4 (VDD1), U2.G9 (VDD1), U2.T4 (VDD1), U2.T9 (VDD1), U2.U1 (VDD1), U2.U12 (VDD1); also elsewhere on the board
/DRAM/SA0: U1.U17 (SA1), U2.H2 (CA0_A), U2.R2 (CA0_B)
/DRAM/SA1: U1.V17 (SCS0), U2.J2 (CA1_A), U2.P2 (CA1_B)
/DRAM/SA2: U1.T21 (SA0), U2.H9 (CA2_A), U2.R9 (CA2_B)
/DRAM/SA3: U1.R20 (SCS1), U2.H10 (CA3_A), U2.R10 (CA3_B)
/DRAM/SA4: U1.R18 (SA4), U2.H11 (CA4_A), U2.R11 (CA4_B)
/DRAM/SA5: U1.T16 (SA3), U2.J11 (CA5_A), U2.P11 (CA5_B)
/DRAM/SCKE0: U1.V15 (SCKE0), U2.J4 (CKE0_A), U2.P4 (CKE0_B)
/DRAM/SCKE1: U1.P13 (SCKE1), U2.J5 (CKE1_A), U2.P5 (CKE1_B)
/DRAM/SCKN: C7.2, R4.2, U1.U14 (SCKN), U2.J9 (CK_C_A), U2.P9 (CK_C_B)
/DRAM/SCKP: C7.1, R4.1, U1.T14 (SCKP), U2.J8 (CK_T_A), U2.P8 (CK_T_B)
/DRAM/SCS0: U1.T18 (SA2), U2.H4 (CS0_A), U2.R4 (CS0_B)
/DRAM/SCS1: U1.P15 (SA5), U2.H3 (CS1_A), U2.R3 (CS1_B)
/DRAM/SDQ0: U1.N3 (SDQ0), U2.U11 (DQ11_B)
/DRAM/SDQ1: U1.U4 (SDQ1), U2.U9 (DQ12_B)
/DRAM/SDQ2: U1.N2 (SDQ2), U2.V11 (DQ10_B)
/DRAM/SDQ3: U1.T4 (SDQ3), U2.V9 (DQ13_B)
/DRAM/SDQ4: U1.U3 (SDQ4), U2.Y9 (DQ14_B)
/DRAM/SDQ5: U1.P1 (SDQ5), U2.AA11 (DQ8_B)
/DRAM/SDQ6: U1.T2 (SDQ6), U2.AA9 (DQ15_B)
/DRAM/SDQ7: U1.P2 (SDQ7), U2.Y11 (DQ9_B)
/DRAM/SDQ8: U1.P5 (SDQ8), U2.Y4 (DQ6_B)
/DRAM/SDQ9: U1.V3 (SDQ9), U2.V2 (DQ2_B)
/DRAM/SDQ10: U1.P4 (SDQ10), U2.Y2 (DQ1_B)
/DRAM/SDQ11: U1.R4 (SDQ11), U2.V4 (DQ5_B)
/DRAM/SDQ12: U1.R6 (SDQ12), U2.U2 (DQ3_B)
/DRAM/SDQ13: U1.N4 (SDQ13), U2.AA2 (DQ0_B)
/DRAM/SDQ14: U1.P6 (SDQ14), U2.U4 (DQ4_B)
/DRAM/SDQ15: U1.N5 (SDQ15), U2.AA4 (DQ7_B)
/DRAM/SDQ16: U1.T11 (SDQ16), U2.C4 (DQ6_A)
/DRAM/SDQ17: U1.U12 (SDQ17), U2.F4 (DQ4_A)
/DRAM/SDQ18: U1.T12 (SDQ18), U2.E4 (DQ5_A)
/DRAM/SDQ19: U1.U9 (SDQ19), U2.B4 (DQ7_A)
/DRAM/SDQ20: U1.T6 (SDQ20), U2.C2 (DQ1_A)
/DRAM/SDQ21: U1.U5 (SDQ21), U2.F2 (DQ3_A)
/DRAM/SDQ22: U1.T7 (SDQ22), U2.B2 (DQ0_A)
/DRAM/SDQ23: U1.T5 (SDQ23), U2.E2 (DQ2_A)
/DRAM/SDQ24: U1.R9 (SDQ24), U2.C9 (DQ14_A)
/DRAM/SDQ25: U1.P7 (SDQ25), U2.E9 (DQ13_A)
/DRAM/SDQ26: U1.N7 (SDQ26), U2.F9 (DQ12_A)
/DRAM/SDQ27: U1.P9 (SDQ27), U2.B11 (DQ8_A)
/DRAM/SDQ28: U1.P10 (SDQ28), U2.C11 (DQ9_A)
/DRAM/SDQ29: U1.U11 (SDQ29), U2.F11 (DQ11_A)
/DRAM/SDQ30: U1.P12 (SDQ30), U2.B9 (DQ15_A)
/DRAM/SDQ31: U1.R12 (SDQ31), U2.E11 (DQ10_A)
/DRAM/SDQM0: U1.U1 (SDQM0), U2.Y10 (DMI1_B)
/DRAM/SDQM1: U1.R3 (SDQM1), U2.Y3 (DMI0_B)
/DRAM/SDQM2: U1.T9 (SDQM2), U2.C3 (DMI0_A)
/DRAM/SDQM3: U1.N10 (SDQM3), U2.C10 (DMI1_A)
/DRAM/SDQS0N: U1.R1 (SDQS0N), U2.V10 (DQS1_C_B)
/DRAM/SDQS0P: U1.R2 (SDQS0P), U2.W10 (DQS1_T_B)
/DRAM/SDQS1N: U1.V2 (SDQS1N), U2.V3 (DQS0_C_B)
/DRAM/SDQS1P: U1.U2 (SDQS1P), U2.W3 (DQS0_T_B)
/DRAM/SDQS2N: U1.U8 (SDQS2N), U2.E3 (DQS0_C_A)
/DRAM/SDQS2P: U1.V8 (SDQS2P), U2.D3 (DQS0_T_A)
/DRAM/SDQS3N: U1.U10 (SDQS3N), U2.E10 (DQS1_C_A)
/DRAM/SDQS3P: U1.V10 (SDQS3P), U2.D10 (DQS1_T_A)
/DRAM/SRST: U1.U21 (SRST), U2.T11 (RESET_N)
GND: C4.2, C5.2, C6.2, C8.2, C9.2, C10.2, C11.2, C12.2, C13.2, C14.2, R3.2, U2.A3 (VSS), U2.A10 (VSS), U2.AB3 (VSS), U2.AB5 (VSS), U2.AB8 (VSS), U2.AB10 (VSS), U2.C1 (VSS), U2.C5 (VSS), U2.C8 (VSS), U2.C12 (VSS), U2.D2 (VSS), U2.D4 (VSS), U2.D9 (VSS), U2.D11 (VSS), U2.E1 (VSS), U2.E5 (VSS), U2.E8 (VSS), U2.E12 (VSS), U2.G1 (VSS), U2.G3 (VSS), U2.G5 (VSS), U2.G8 (VSS), U2.G10 (VSS), U2.G12 (VSS), U2.J1 (VSS), U2.J3 (VSS), U2.J10 (VSS), U2.J12 (VSS), U2.K2 (VSS), U2.K4 (VSS), U2.K9 (VSS), U2.K11 (VSS), U2.N2 (VSS), U2.N4 (VSS), U2.N9 (VSS), U2.N11 (VSS), U2.P1 (VSS), U2.P3 (VSS), U2.P10 (VSS), U2.P12 (VSS), U2.T1 (VSS), U2.T3 (VSS), U2.T5 (VSS), U2.T8 (VSS), U2.T10 (VSS), U2.T12 (VSS), U2.V1 (VSS), U2.V5 (VSS), U2.V8 (VSS), U2.V12 (VSS), U2.W2 (VSS), U2.W4 (VSS), U2.W9 (VSS), U2.W11 (VSS), U2.Y1 (VSS), U2.Y5 (VSS), U2.Y8 (VSS), U2.Y12 (VSS); also elsewhere on the board
unnamed: R3.1, U1.L15 (SZQ)
unnamed: R1.1, U2.G2 (ODT_CA_A)
unnamed: R2.1, U2.T2 (ODT_CA_B)
unnamed: R6.1, U2.A5 (ZQ0)
unnamed: R5.1, U2.A8 (ZQ1)
VCC_DRAM: C4.1, C5.1, C6.1, C8.1, C9.1, C10.1, C11.1, C12.1, C13.1, R1.2, R2.2, R5.2, R6.2, U1.L9 (VCC_DRAM1), U1.L10 (VCC_DRAM2), U1.L11 (VCC_DRAM3), U1.L12 (VCC_DRAM4), U1.L13 (VCC_DRAM5), U2.A4 (VDD2), U2.A9 (VDD2), U2.AA3 (VDDQ), U2.AA5 (VDDQ), U2.AA8 (VDDQ), U2.AA10 (VDDQ), U2.AB4 (VDD2), U2.AB9 (VDD2), U2.B3 (VDDQ), U2.B5 (VDDQ), U2.B8 (VDDQ), U2.B10 (VDDQ), U2.D1 (VDDQ), U2.D5 (VDDQ), U2.D8 (VDDQ), U2.D12 (VDDQ), U2.F3 (VDDQ), U2.F5 (VDD2), U2.F8 (VDD2), U2.F10 (VDDQ), U2.H1 (VDD2), U2.H5 (VDD2), U2.H8 (VDD2), U2.H12 (VDD2), U2.K1 (VDD2), U2.K3 (VDD2), U2.K10 (VDD2), U2.K12 (VDD2), U2.N1 (VDD2), U2.N3 (VDD2), U2.N10 (VDD2), U2.N12 (VDD2), U2.R1 (VDD2), U2.R5 (VDD2), U2.R8 (VDD2), U2.R12 (VDD2), U2.U3 (VDDQ), U2.U5 (VDD2), U2.U8 (VDD2), U2.U10 (VDDQ), U2.W1 (VDDQ), U2.W5 (VDDQ), U2.W8 (VDDQ), U2.W12 (VDDQ); also elsewhere on the board

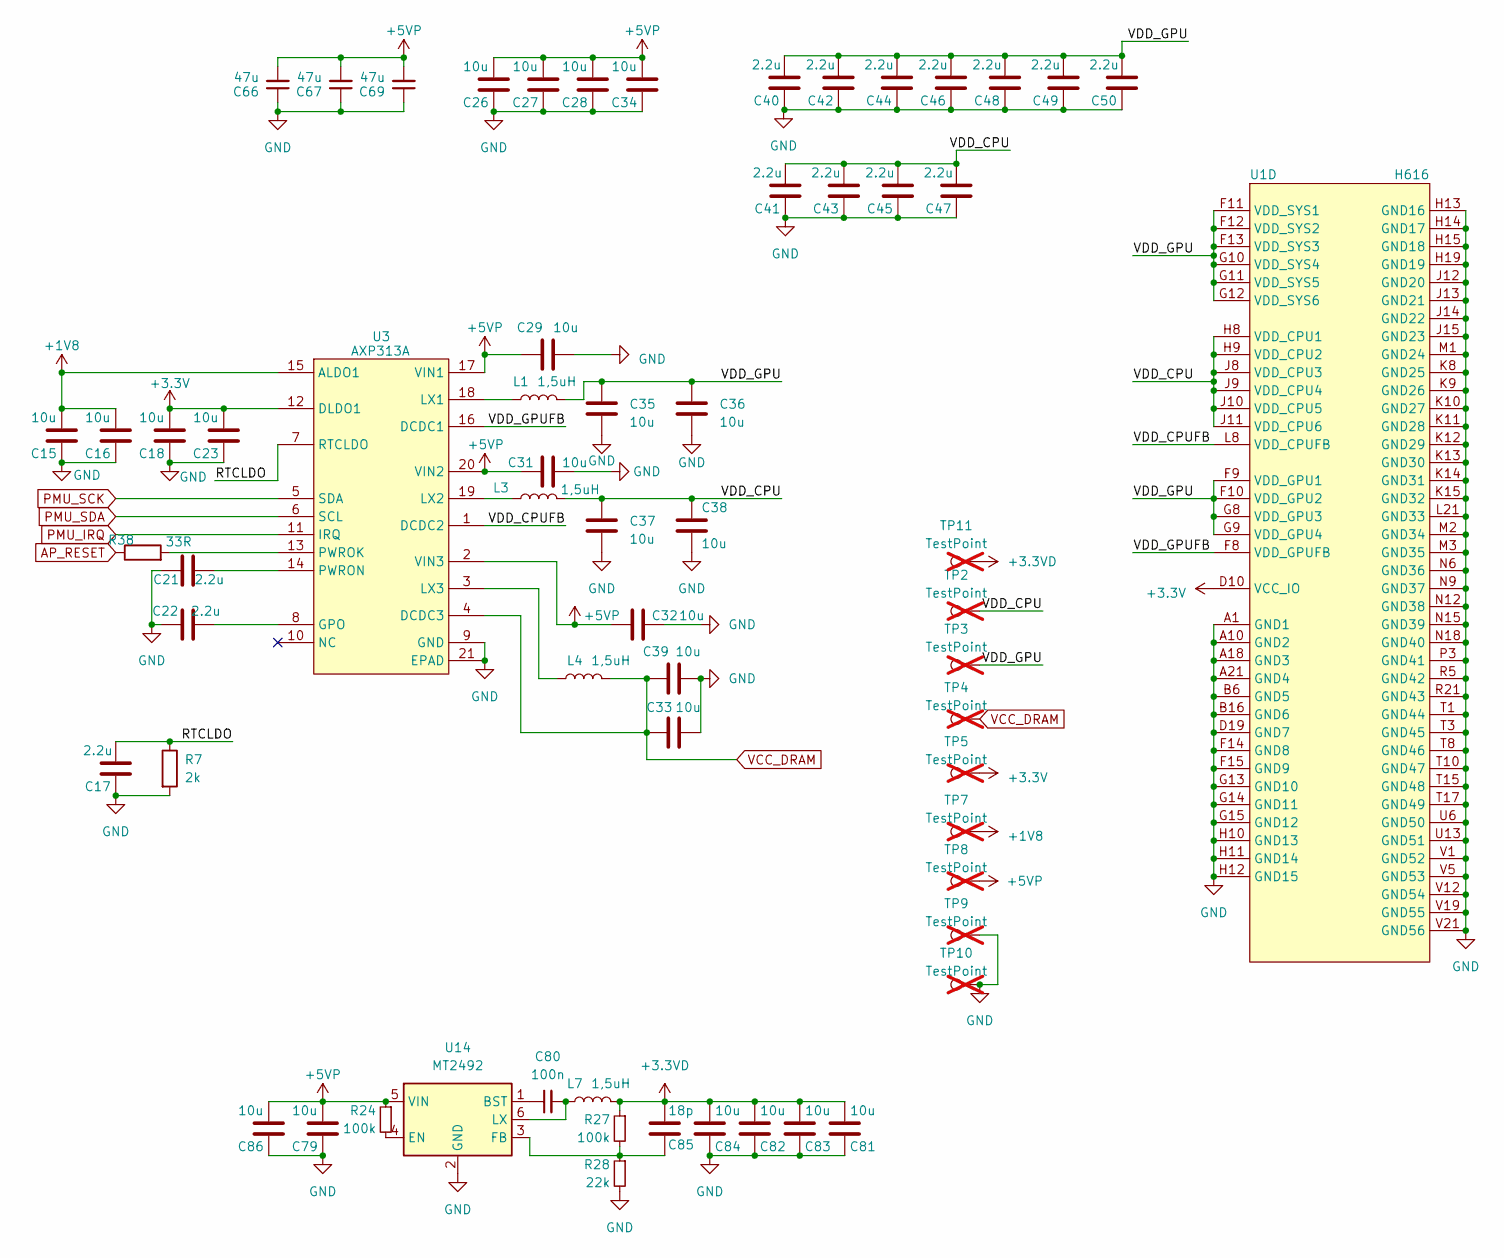
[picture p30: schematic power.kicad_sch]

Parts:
C15, C16, C18, C23, C26, C27, C28, C29, C31, C32, C33, C34, C35, C36, C37, C38, C39, C79, C81, C82, C83, C84, C86: 10u; C_0402_1005Metric_Pad0.74x0.62mm_HandSolder; Part Number GRM155R61A106ME44D
C17, C21, C22, C40, C41, C42, C43, C44, C45, C46, C47, C48, C49, C50: 2.2u; C_0402_1005Metric_Pad0.74x0.62mm_HandSolder; Part Number CL05A225KO5NQNC
C66, C67, C69: 47u; C_1210_3225Metric_Pad1.33x2.70mm_HandSolder; Part Number CS3225X7R476K160NRL
C80: 100n; C_0402_1005Metric_Pad0.74x0.62mm_HandSolder; Part Number CL05B104KO5NNNC
C85: 18p; C_0402_1005Metric_Pad0.74x0.62mm_HandSolder; Part Number 0402CG180J500NT
L1, L3, L4, L7: 1,5uH; L_Changjiang_FNR252010S; Part Number FTC252012S2R2MBCA
R7: 2k; R_0402_1005Metric_Pad0.72x0.64mm_HandSolder; Part Number RC0402FR-072KL
R24, R27: 100k; R_0402_1005Metric_Pad0.72x0.64mm_HandSolder; Part Number RC0402FR-07100KL
R28: 22k; R_0402_1005Metric_Pad0.72x0.64mm_HandSolder; Part Number RC0402FR-0722KL
R38: 33R; R_0402_1005Metric_Pad0.72x0.64mm_HandSolder; Part Number RC0402FR-0733RL
TP2, TP3, TP4, TP5, TP7, TP8, TP9, TP10, TP11: TestPoint; TestPoint_THTPad_D1.0mm_Drill0.5mm; not fitted
U1: H616; H616_TFBGA284; Part Number H616
U3: QFN-20-1EP_3x3mm_P0.4mm_EP1.65x1.65mm_ThermalVias; Part Number AXP313A
U14: MT2492; SOT-23-6; Part Number MT2492

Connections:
+1V8: C15.2, C16.2, TP7.1, U3.15 (ALDO1); also elsewhere on the board
+3.3V: C18.2, C23.2, TP5.1, U1.D10 (VCC_IO), U3.12 (DLDO1); also elsewhere on the board
+3.3VD: C81.2, C82.2, C83.2, C84.2, C85.2, L7.2, R27.1, TP11.1; also elsewhere on the board
+5VP: C26.2, C27.2, C28.2, C29.1, C31.1, C32.1, C34.2, C66.2, C67.2, C69.2, C79.2, C86.2, R24.1, TP8.1, U3.2 (VIN3), U3.17 (VIN1), U3.20 (VIN2), U14.5 (VIN); also elsewhere on the board
/POWER/RTCLDO: C17.2, R7.1, U3.7 (RTCLDO)
/POWER/VDD_CPU: C37.1, C38.2, C41.2, C43.2, C45.2, C47.2, L3.2, TP2.1, U1.H8 (VDD_CPU1), U1.H9 (VDD_CPU2), U1.J8 (VDD_CPU3), U1.J9 (VDD_CPU4), U1.J10 (VDD_CPU5), U1.J11 (VDD_CPU6)
/POWER/VDD_CPUFB: U1.L8 (VDD_CPUFB), U3.1 (DCDC2)
/POWER/VDD_GPU: C35.1, C36.1, C40.2, C42.2, C44.2, C46.2, C48.2, C49.2, C50.2, L1.2, TP3.1, U1.F9 (VDD_GPU1), U1.F10 (VDD_GPU2), U1.F11 (VDD_SYS1), U1.F12 (VDD_SYS2), U1.F13 (VDD_SYS3), U1.G8 (VDD_GPU3), U1.G9 (VDD_GPU4), U1.G10 (VDD_SYS4), U1.G11 (VDD_SYS5), U1.G12 (VDD_SYS6)
/POWER/VDD_GPUFB: U1.F8 (VDD_GPUFB), U3.16 (DCDC1)
AP_RESET: R38.1; also elsewhere on the board
GND: C15.1, C16.1, C17.1, C18.1, C21.1, C22.1, C23.1, C26.1, C27.1, C28.1, C29.2, C31.2, C32.2, C33.2, C34.1, C35.2, C36.2, C37.2, C38.1, C39.2, C40.1, C41.1, C42.1, C43.1, C44.1, C45.1, C46.1, C47.1, C48.1, C49.1, C50.1, C66.1, C67.1, C69.1, C79.1, C81.1, C82.1, C83.1, C84.1, C86.1, R7.2, R28.2, TP9.1, TP10.1, U1.A1 (GND1), U1.A10 (GND2), U1.A18 (GND3), U1.A21 (GND4), U1.B6 (GND5), U1.B16 (GND6), U1.D19 (GND7), U1.F14 (GND8), U1.F15 (GND9), U1.G13 (GND10), U1.G14 (GND11), U1.G15 (GND12), U1.H10 (GND13), U1.H11 (GND14), U1.H12 (GND15), U1.H13 (GND16), U1.H14 (GND17), U1.H15 (GND18), U1.H19 (GND19), U1.J12 (GND20), U1.J13 (GND21), U1.J14 (GND22), U1.J15 (GND23), U1.K8 (GND25), U1.K9 (GND26), U1.K10 (GND27), U1.K11 (GND28), U1.K12 (GND29), U1.K13 (GND30), U1.K14 (GND31), U1.K15 (GND32), U1.L21 (GND33), U1.M1 (GND24), U1.M2 (GND34), U1.M3 (GND35), U1.N6 (GND36), U1.N9 (GND37), U1.N12 (GND38), U1.N15 (GND39), U1.N18 (GND40), U1.P3 (GND41), U1.R5 (GND42), U1.R21 (GND43), U1.T1 (GND44), U1.T3 (GND45), U1.T8 (GND46), U1.T10 (GND47), U1.T15 (GND48), U1.T17 (GND49), U1.U6 (GND50), U1.U13 (GND51), U1.V1 (GND52), U1.V5 (GND53), U1.V12 (GND54), U1.V19 (GND55), U1.V21 (GND56), U3.9 (GND), U3.21 (EPAD), U14.2 (GND); also elsewhere on the board
unnamed: C22.2, U3.8 (GPO)
unnamed: L1.1, U3.18 (LX1)
unnamed: L3.1, U3.19 (LX2)
unnamed: L4.1, U3.3 (LX3)
unnamed: R38.2, U3.13 (PWROK)
unnamed: C21.2, U3.14 (PWRON)
unnamed: C80.1, U14.1 (BST)
unnamed: R24.2, U14.4 (EN)
unnamed: C85.1, R27.2, R28.1, U14.3 (FB)
unnamed: C80.2, L7.1, U14.6 (LX)
PMU_IRQ: U3.11 (IRQ); also elsewhere on the board
PMU_SCK: U3.5 (SDA); also elsewhere on the board
PMU_SDA: U3.6 (SCL); also elsewhere on the board
VCC_DRAM: C33.1, C39.1, L4.2, TP4.1, U3.4 (DCDC3); also elsewhere on the board

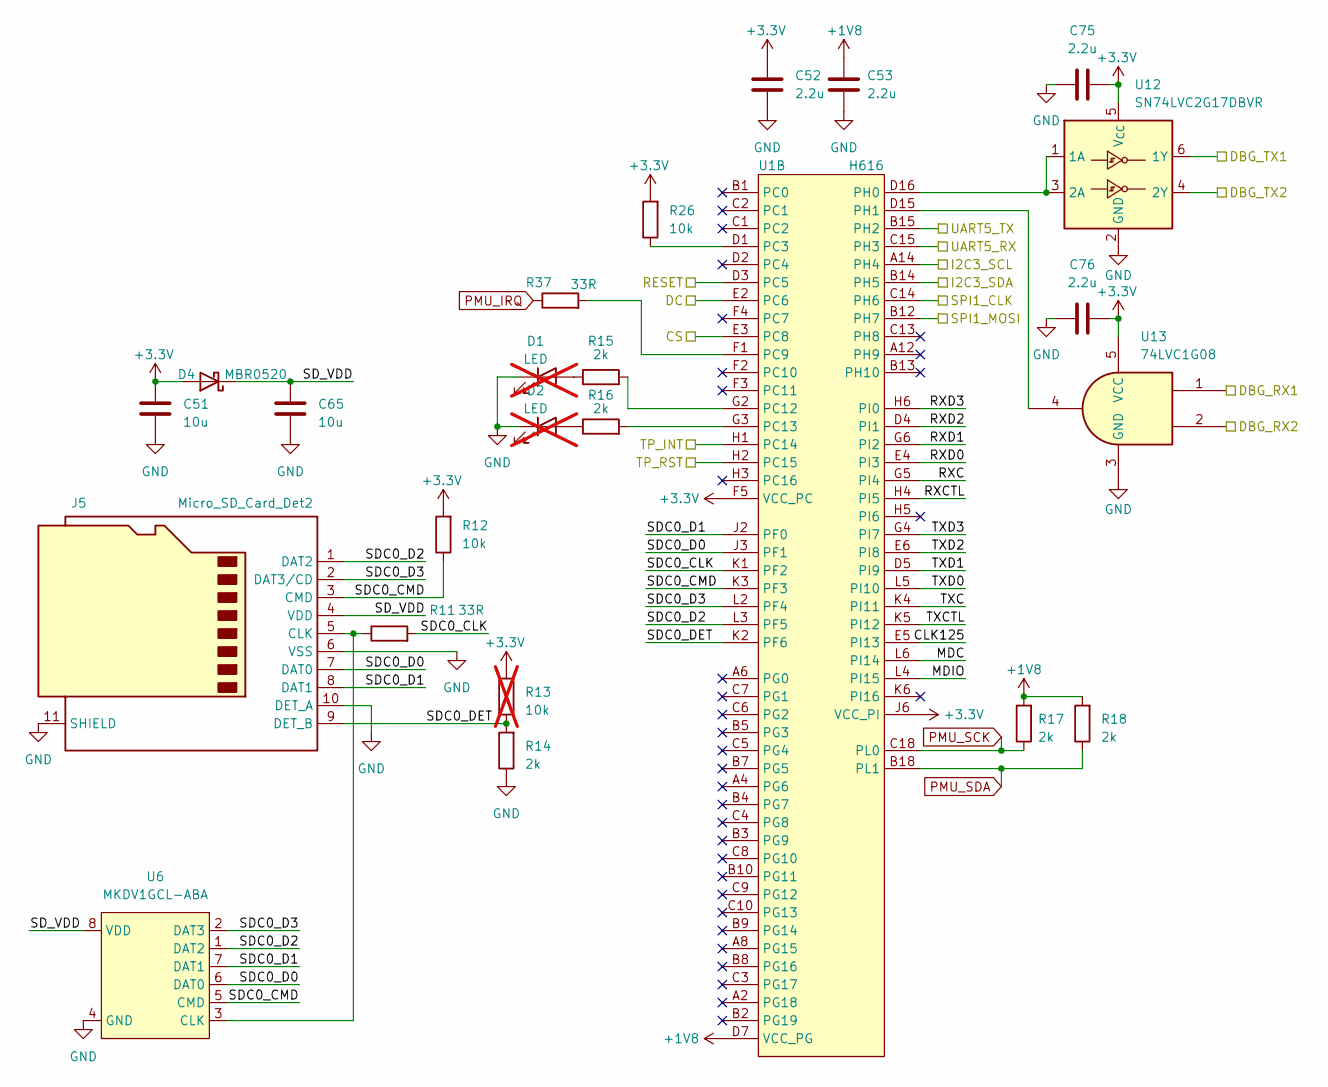
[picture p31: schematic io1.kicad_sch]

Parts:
C51, C65: 10u; C_0402_1005Metric_Pad0.74x0.62mm_HandSolder; Part Number GRM155R61A106ME44D
C52, C53, C75, C76: 2.2u; C_0402_1005Metric_Pad0.74x0.62mm_HandSolder; Part Number CL05A225KO5NQNC
D1, D2: LED; LED_0603_1608Metric_Pad1.05x0.95mm_HandSolder; not fitted
D4: MBR0520; D_SOD-123; Part Number MBR0520
J5: Micro_SD_Card_Det2; microSD_HC_Hirose_DM3AT-SF-PEJM5; Part Number HRS(Hirose)
R11, R37: 33R; R_0402_1005Metric_Pad0.72x0.64mm_HandSolder; Part Number RC0402FR-0733RL
R12, R26: 10k; R_0402_1005Metric_Pad0.72x0.64mm_HandSolder; Part Number RC0402FR-0710KL
R13: 10k; R_0402_1005Metric_Pad0.72x0.64mm_HandSolder; not fitted
R14, R15, R16, R17, R18: 2k; R_0402_1005Metric_Pad0.72x0.64mm_HandSolder; Part Number RC0402FR-072KL
U1: H616; H616_TFBGA284; Part Number H616
U6: MKDV1GCL-ABA; LGA-8_8x6mm_P1.27mm; Part Number MKDV08GCL-STP
U12: SN74LVC2G17DBVR; SOT-23-6; Part Number SN74LVC2G17DBVR(UMW)
U13: 74LVC1G08; SOT-23-5; Part Number 74LVC1G08GV

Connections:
+1V8: C53.1, R17.2, R18.2, U1.D7 (VCC_PG); also elsewhere on the board
+3.3V: C51.1, C52.1, C75.2, C76.2, D4.2 (A), R12.2, R13.2, R26.2, U1.F5 (VCC_PC), U1.J6 (VCC_PI), U12.5 (V_{CC}), U13.5 (VCC); also elsewhere on the board
/IO1/CLK125: U1.E5 (PI13)
/IO1/CS: U1.E3 (PC8); also elsewhere on the board
/IO1/DBG_RX1: U13.1; also elsewhere on the board
/IO1/DBG_RX2: U13.2; also elsewhere on the board
/IO1/DBG_TX1: U12.6 (1Y); also elsewhere on the board
/IO1/DBG_TX2: U12.4 (2Y); also elsewhere on the board
/IO1/DC: U1.E2 (PC6); also elsewhere on the board
/IO1/MDC: U1.L6 (PI14)
/IO1/MDIO: U1.L4 (PI15)
/IO1/RESET: U1.D3 (PC5); also elsewhere on the board
/IO1/RXC: U1.G5 (PI4)
/IO1/RXCTL: U1.H4 (PI5)
/IO1/RXD0: U1.E4 (PI3)
/IO1/RXD1: U1.G6 (PI2)
/IO1/RXD2: U1.D4 (PI1)
/IO1/RXD3: U1.H6 (PI0)
/IO1/SDC0_CLK: R11.2, U1.K1 (PF2)
/IO1/SDC0_CMD: J5.3 (CMD), R12.1, U1.K3 (PF3), U6.5 (CMD)
/IO1/SDC0_D0: J5.7 (DAT0), U1.J3 (PF1), U6.6 (DAT0)
/IO1/SDC0_D1: J5.8 (DAT1), U1.J2 (PF0), U6.7 (DAT1)
/IO1/SDC0_D2: J5.1 (DAT2), U1.L3 (PF5), U6.1 (DAT2)
/IO1/SDC0_D3: J5.2 (DAT3/CD), U1.L2 (PF4), U6.2 (DAT3)
/IO1/SDC0_DET: J5.9 (DET_B), R13.1, R14.2, U1.K2 (PF6)
/IO1/SD_VDD: C65.1, D4.1 (K), J5.4 (VDD), U6.8 (VDD)
/IO1/SPI1_CLK: U1.C14 (PH6); also elsewhere on the board
/IO1/SPI1_MOSI: U1.B12 (PH7); also elsewhere on the board
/IO1/TXC: U1.K4 (PI11)
/IO1/TXCTL: U1.K5 (PI12)
/IO1/TXD0: U1.L5 (PI10)
/IO1/TXD1: U1.D5 (PI9)
/IO1/TXD2: U1.E6 (PI8)
/IO1/TXD3: U1.G4 (PI7)
/IO1/UART5_RX: U1.C15 (PH3); also elsewhere on the board
/IO1/UART5_TX: U1.B15 (PH2); also elsewhere on the board
/TP_INT: U1.H1 (PC14); also elsewhere on the board
/TP_RST: U1.H2 (PC15); also elsewhere on the board
/TP_SCL: U1.A14 (PH4); also elsewhere on the board
/TP_SDA: U1.B14 (PH5); also elsewhere on the board
GND: C51.2, C52.2, C53.2, C65.2, C75.1, C76.1, D1.1 (K), D2.1 (K), J5.6 (VSS), J5.10 (DET_A), J5.11 (SHIELD), R14.1, U6.4 (GND), U12.2 (GND), U13.3 (GND); also elsewhere on the board
unnamed: D1.2 (A), R15.1
unnamed: D2.2 (A), R16.1
unnamed: J5.5 (CLK), R11.1, U6.3 (CLK)
unnamed: R26.1, U1.D1 (PC3)
unnamed: R37.2, U1.F1 (PC9)
unnamed: R15.2, U1.G2 (PC12)
unnamed: R16.2, U1.G3 (PC13)
unnamed: U1.D15 (PH1), U13.4
unnamed: U1.D16 (PH0), U12.1 (1A), U12.3 (2A)
PMU_IRQ: R37.1; also elsewhere on the board
PMU_SCK: R17.1, U1.C18 (PL0); also elsewhere on the board
PMU_SDA: R18.1, U1.B18 (PL1); also elsewhere on the board


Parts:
C70, C71, C72, C73, C74: 2.2u; C_0402_1005Metric_Pad0.74x0.62mm_HandSolder; Part Number CL05A225KO5NQNC
U7, U8, U9, U10, U11: SOT-23-6; Part Number SN74LVC1G157DB(LX)

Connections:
+3.3VD: C70.2, C71.2, C72.2, C73.2, C74.2, U7.5 (VCC), U8.5 (VCC), U9.5 (VCC), U10.5 (VCC), U11.5 (VCC); also elsewhere on the board
/CLK: U9.4 (Y); also elsewhere on the board
/CS: U11.4 (Y); also elsewhere on the board
/DC: U10.4 (Y); also elsewhere on the board
/IO1/CS: U11.3 (I0); also elsewhere on the board
/IO1/DC: U10.3 (I0); also elsewhere on the board
/IO1/RESET: U7.3 (I0); also elsewhere on the board
/IO1/SPI1_CLK: U9.3 (I0); also elsewhere on the board
/IO1/SPI1_MOSI: U8.3 (I0); also elsewhere on the board
/MCU/CS: U11.1 (I1); also elsewhere on the board
/MCU/DC: U10.1 (I1); also elsewhere on the board
/MCU/MCU_SOC_SLCT: U7.6 (S), U8.6 (S), U9.6 (S), U10.6 (S), U11.6 (S); also elsewhere on the board
/MCU/RESET: U7.1 (I1); also elsewhere on the board
/MCU/SPI1_CLK: U9.1 (I1); also elsewhere on the board
/MCU/SPI1_MOSI: U8.1 (I1); also elsewhere on the board
/MOSI: U8.4 (Y); also elsewhere on the board
/RESET: U7.4 (Y); also elsewhere on the board
GND: C70.1, C71.1, C72.1, C73.1, C74.1, U7.2 (GND), U8.2 (GND), U9.2 (GND), U10.2 (GND), U11.2 (GND); also elsewhere on the board


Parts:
C54, C55, C58, C61, C62, C63, C64: 100n; C_0402_1005Metric_Pad0.74x0.62mm_HandSolder; Part Number CL05B104KO5NNNC
C56, C57: 2.2u; C_0402_1005Metric_Pad0.74x0.62mm_HandSolder; Part Number CL05A225KO5NQNC
C59, C60: 18p; C_0402_1005Metric_Pad0.74x0.62mm_HandSolder; Part Number 0402CG180J500NT
R19: 150k; R_0402_1005Metric_Pad0.72x0.64mm_HandSolder; Part Number RC0402FR-07150KL
R20: 10k; R_0402_1005Metric_Pad0.72x0.64mm_HandSolder; Part Number RC0402FR-0710KL
U1: H616; H616_TFBGA284; Part Number H616
Y1: 24MHz; Crystal_SMD_2520-4Pin_2.5x2.0mm; Part Number XTM25024000JT00351001

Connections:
+1V8: C58.1, U1.D11 (VCC_DCXO), U1.D12 (VCC_PLL), U1.F18 (VCC_HDMI), U1.H17 (AVCC), U1.H20 (VCC_TV); also elsewhere on the board
+3.3V: C61.1, C62.1, R20.1, U1.E18 (VCC_EPHY), U1.M18 (VCC_USB); also elsewhere on the board
/AUX_D+: U1.J20 (USB0_DP); also elsewhere on the board
/AUX_D-: U1.J19 (USB0_DM); also elsewhere on the board
/CODEC_D+: U1.K20 (USB2_DP); also elsewhere on the board
/CODEC_D-: U1.K19 (USB2_DM); also elsewhere on the board
/IO2/SOC_XIN: C59.2, U1.B11 (DXIN), Y1.3
/IO2/SOC_XOUT: C60.2, U1.C12 (DXOUT), Y1.1
/IO2/TV_OUT: U1.J21 (TV_OUT)
/IO2/USB3_D+: U1.L20 (USB3_DP)
/IO2/USB3_D-: U1.L19 (USB3_DM)
/MCU_D+: U1.M20 (USB1_DP); also elsewhere on the board
/MCU_D-: U1.M19 (USB1_DM); also elsewhere on the board
AP_RESET: C64.1, R20.2, U1.A16 (RESET); also elsewhere on the board
GND: C54.2, C55.2, C56.2, C57.2, C58.2, C59.1, C60.1, C61.2, C62.2, C63.2, C64.2, R19.2, U1.H18 (AGND), Y1.2, Y1.4; also elsewhere on the board
unnamed: C56.1, U1.D18 (AC_AVCC)
unnamed: C57.1, U1.C17 (AC_VRA1)
unnamed: C63.1, U1.D13 (DXLDO_OUT)
unnamed: R19.1, U1.K18 (REXT)
unnamed: C54.1, U1.J18 (VRA1)
unnamed: C55.1, U1.J17 (VRA2)


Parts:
C68: 2.2u; C_0402_1005Metric_Pad0.74x0.62mm_HandSolder; Part Number CL05A225KO5NQNC
R25: 10k; R_0402_1005Metric_Pad0.72x0.64mm_HandSolder; Part Number RC0402FR-0710KL
U4: CP2102N-Axx-xQFN28; QFN-28-1EP_5x5mm_P0.5mm_EP3.35x3.35mm; Part Number CP2102-GMR

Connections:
+5VP: C68.1, U4.7 (VREGIN), U4.8 (VBUS); also elsewhere on the board
/DBG_D+: U4.4 (D+); also elsewhere on the board
/DBG_D-: U4.5 (D-); also elsewhere on the board
/IO1/DBG_RX1: U4.26 (TXD); also elsewhere on the board
/IO1/DBG_TX1: U4.25 (RXD); also elsewhere on the board
GND: C68.2, U4.3 (GND), U4.29 (GND); also elsewhere on the board
unnamed: R25.1, U4.6 (VDD)
unnamed: R25.2, U4.9 (~RST)

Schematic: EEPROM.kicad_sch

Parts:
C94: 2.2u; C_0402_1005Metric_Pad0.74x0.62mm_HandSolder; Part Number CL05A225KO5NQNC
D3: MBR0520; D_SOD-123; Part Number MBR0520
R31, R32: 10k; R_0402_1005Metric_Pad0.72x0.64mm_HandSolder; Part Number RC0402FR-0710KL
U17: M24C02-FMN; SOIC-8_3.9x4.9mm_P1.27mm; Part Number M24C02-WMN6TP

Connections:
+3.3V: D3.2 (A); also elsewhere on the board
/TP_SCL: R32.1, U17.6 (SCL); also elsewhere on the board
/TP_SDA: R31.1, U17.5 (SDA); also elsewhere on the board
GND: C94.1, U17.1 (E0), U17.2 (E1), U17.3 (E2), U17.4 (VSS), U17.7 (~WC); also elsewhere on the board
unnamed: C94.2, D3.1 (K), R31.2, R32.2, U17.8 (VCC)



Board: 4 copper layers, 58.0 x 66.0 mm, 165 parts (44 on the bottom side), 174 nets.

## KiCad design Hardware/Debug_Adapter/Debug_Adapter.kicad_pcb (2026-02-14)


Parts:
C1, C2, C3, C4, C5: 10u; C_0402_1005Metric_Pad0.74x0.62mm_HandSolder; Part Number GRM155R61A106ME44D
C7, C8, C9, C10: 47u; C_1210_3225Metric_Pad1.33x2.70mm_HandSolder; Part Number CS3225X7R476K160NRL
D1, D2: SMAJ5.0A; D_SMA; Part Number SMAJ5.0A
F1, F2: Fuse_Small; Fuse_1812_4532Metric_Pad1.30x3.40mm_HandSolder; Part Number SMD1812-200C-30V
J2, J6, J7: USB_C_Receptacle_USB2.0_16P; USB_C_Receptacle_GCT_USB4105-xx-A_16P_TopMnt_Horizontal; Part Number TYPE-C-31-M-12
J3: Conn_01x08_MountingPin; TE_84952-8_1x08-1MP_P1.0mm_Horizontal; Part Number XW10202-08R-00
J5: Conn_01x20_MountingPin; TE_2-84952-0_1x20-1MP_P1.0mm_Horizontal; Part Number XW10202-20R-00
R2, R3, R4, R5: 5K1; R_0402_1005Metric; Part Number RC0402FR-075K1L
R6, R7: 22K; R_0402_1005Metric; Part Number RC0402FR-0722KL
U1: GL823K; SSOP-16_3.9x4.9mm_P0.635mm; Part Number Genesys Logic

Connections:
+5V: C1.2, C2.2, C7.2, D1.1 (A1), F1.2, U1.10 (5V)
+5VP: C8.2, C9.2, C10.2, D2.1 (A1), F2.2, J5.19, J5.20, J7.A4 (VBUS), J7.A9 (VBUS), J7.B4 (VBUS), J7.B9 (VBUS), R6.1, R7.1
/AUX_D+: J5.12, J7.A6 (D+), J7.B6 (D+)
/AUX_D-: J5.13, J7.A7 (D-), J7.B7 (D-)
/D+: J2.A6 (D+), J2.B6 (D+), U1.15 (DP)
/D-: J2.A7 (D-), J2.B7 (D-), U1.16 (DM)
/DBG_D+: J5.16, J6.A6 (D+), J6.B6 (D+)
/DBG_D-: J5.17, J6.A7 (D-), J6.B7 (D-)
/SDC0_CMD: J3.5, U1.5 (CMD)
/SDC0_D0: J3.3, U1.3 (D0)
/SDC0_D1: J3.2, U1.2 (D1)
/SDC0_D2: J3.7, U1.7 (D2)
/SDC0_D3: J3.6, U1.6 (D3)
/SD_CLK: J3.4, U1.4 (CLK)
/SD_VSS: C5.2, J3.8, U1.8 (PMOS)
GND: C1.1, C2.1, C3.1, C4.1, C5.1, C7.1, C8.1, C9.1, C10.1, D1.2 (A2), D2.2 (A2), J2.A1 (GND), J2.A12 (GND), J2.B1 (GND), J2.B12 (GND), J2.S1 (SHIELD), J3.1, J3.MP (MountPin), J5.1, J5.2, J5.3, J5.MP (MountPin), J6.A1 (GND), J6.A12 (GND), J6.B1 (GND), J6.B12 (GND), J6.S1 (SHIELD), J7.A1 (GND), J7.A12 (GND), J7.B1 (GND), J7.B12 (GND), J7.S1 (SHIELD), R2.1, R3.1, R4.1, R5.1, U1.1 (VSS), U1.14 (VSS)
unnamed: F1.1, J2.A4 (VBUS), J2.A9 (VBUS), J2.B4 (VBUS), J2.B9 (VBUS)
unnamed: F2.1, J6.A4 (VBUS), J6.A9 (VBUS), J6.B4 (VBUS), J6.B9 (VBUS)
unnamed: J2.A5 (CC1), R2.2
unnamed: J2.B5 (CC2), R3.2
unnamed: J6.A5 (CC1), R4.2
unnamed: J6.B5 (CC2), R5.2
unnamed: J7.A5 (CC1), R6.2
unnamed: J7.B5 (CC2), R7.2
unnamed: C4.2, U1.9 (VDD)
unnamed: C3.2, U1.13 (VDDA)


Board: 2 copper layers, 39.5 x 56.0 mm, 25 parts (1 on the bottom side), 26 nets.

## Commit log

2024-04-18 fixed crystal resonator value
    [H616_devboard.kicad_pcb, H616_devboard.kicad_sch, dram.kicad_sch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]
2026-02-14 Add new board version with LPDDR4
    [Debug_Adapter.kicad_pcb, Debug_Adapter.kicad_sch, EEPROM.kicad_sch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]
